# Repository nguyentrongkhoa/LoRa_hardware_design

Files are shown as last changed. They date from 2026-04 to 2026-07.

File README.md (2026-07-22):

# 🌍 Overview

This is a 4-layer RF-LoRa-PCB design for my bachelor thesis. The design entails:

1. LoRa transceiver embedded within the STM32WL55 microcontroller
2. BMV080 sensor and BME680 breakout board from Bosch
3. L80-R GPS module from Quectel to test radio coverage
4. SPV1050 solar energy harvesting module
5. BQ24074 battery charging module with USB-C connector

<table>
  <tr>
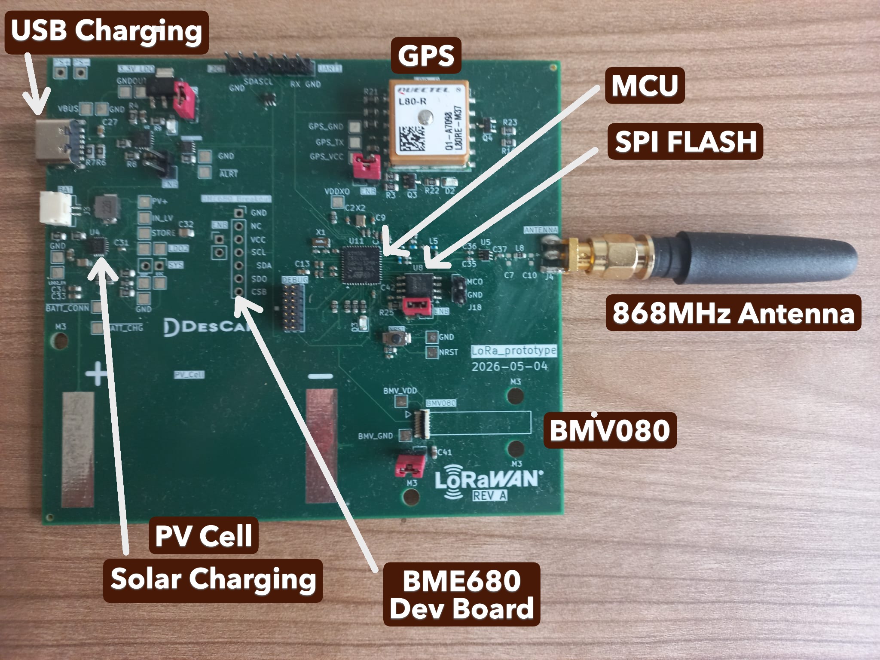
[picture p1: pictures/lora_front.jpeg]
Front
    <td></td>
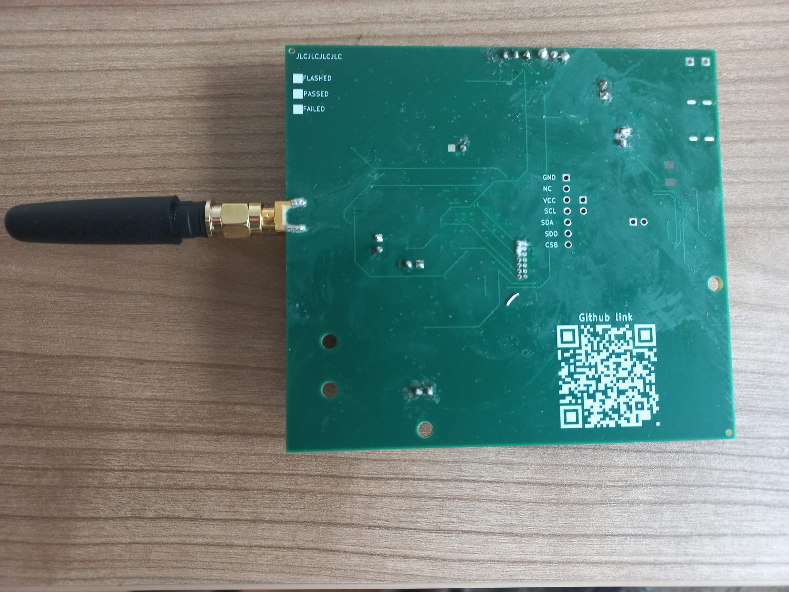
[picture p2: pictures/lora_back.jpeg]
Back
    <td></td>
  </tr>
</table>

<details>
<summary><h1>📋STM32WL55CCU6 pinout configuration</h1>  </summary>

|**Pin number** | **Pin name**| **Description**|
|---|---|---|
|PA0|Blinky LED|To quick test if flashing works
|PA2|VCP_TX|STLinkV3 virtual com port|
|PA3|VCP_RX|STLinkV3 virtual com port|
|PA4|NSS1|SPI1 slave select|
|PA5|SCK1|SPI1 clock signal|
|PA6|MISO1|SPI1|
|PA7|MOSI1|SPI1|
|PA8|MCO|Hook up to oscilloscope to test TCXO 32MHz output|
|PA9 |TX1|UART to communicate with GPS 
|PA10|RX1|UART to communicate with GPS 
|PA12|GPS_RESET|
|PA13|SWDIO|for flashing/debugging
|PA14|SWDCK|for flashing/debugging
|PB2|ALRT|From MAX17048 fuel gauge when battery is low
|PB3|SWO|for flashing/debugging
|PB6|SCL1|I2C to communicate with gas sensors and fuel gauge
|PB7|SDA1|I2C to communicate with gas sensors and fuel gauge
|PB8 |RF_SW_V2| RF switch control input 2 (to choose between receive and transmit)
|PB12|RF_SW_V1| RF switch control input 1
</details>

<details>
  
<summary><h1>🔌Testpoints setup</h1> </summary>

|**Testpoint name** | **Description**| **Expected result**
|---|---|---|
|VBUS|USB voltage|5V when USB is connected
|OUT|output of BQ24074 battery charging module|4.2V when battery is full, ~3.5V when battery empty
|ALRT|MAX17048 fuel gauge alert signal when battery is low|3.3V when battery is full, 0V when empty 

</details>

<details>
<summary><h1>🔍PCB inspection result</h1></summary>
  
## Detailed testing
### Visual inspection
### Electrical tests

#### Power consumption 

</details>

<details>
<summary><h1>✅<b>TODOs for next version</b></h1></summary>

- [ ] Replace SMA connector from Samtec with a cheaper one (see notes in schematic)
- [ ] Tune the antenna side matching network with NanoVNA
- [ ] Remove GPS module since TTFF (time-to-first-fix) is too long
- [ ] Move BMV080 away from MCU
- [ ] Fix VCP (virtual COM port) connections so that debug prints can be displayed in the host comp's terminal
- [ ] Fix PCB edge cut so that it's rectangular and not jagged
- [ ] Fix BMV080 orientation (so that it does not overlap solar cell)
- [ ] Remove USB charging (including BQ24072 charging IC), since the 3.3V LDO of the SPV1050 with max 200 mA can supply the       whole system

</details>

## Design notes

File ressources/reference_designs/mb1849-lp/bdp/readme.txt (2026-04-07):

******************************************************************************
* @file         readme.txt
* @author   MCD Application Team
* @version 1.0
* @date      22-June-2022 
* @brief      Reference_Design_STM32WL_BGA73_4L_IPD_LowPower board manufacturing files package
******************************************************************************
* COPYRIGHT(c) 2022 STMicroelectronics
*
* The Open Platform License Agreement (“Agreement”) is a binding legal contract
* between you ("You") and STMicroelectronics International N.V. (“ST”), a
* company incorporated under the laws of the Netherlands acting for the purpose
* of this Agreement through its Swiss branch 39, Chemin du Champ des Filles,
* 1228 Plan-les-Ouates, Geneva, Switzerland.
*
* By using the enclosed reference designs, schematics, PC board layouts, and
* documentation, in hardcopy or CAD tool file format (collectively, the
* “Reference Material”), You are agreeing to be bound by the terms and
* conditions of this Agreement. Do not use the Reference Material until You
* have read and agreed to this Agreement terms and conditions. The use of
* the Reference Material automatically implies the acceptance of the Agreement
* terms and conditions.
*
* The complete Open Platform License Agreement can be found on www.st.com/opla.
******************************************************************************

========================
* 1.0 - 22-June-2022
========================
    + First official release.
	Manufacturing files and differents BOM variants for the board MB1849-LP

******************* (C) COPYRIGHT 2022 STMicroelectronics *****END OF FILE

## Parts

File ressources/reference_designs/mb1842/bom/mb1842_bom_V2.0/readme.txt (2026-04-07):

******************************************************************************
* @file         readme.txt
* @author   MCD Application Team
* @version 2.0
* @date      28-April-2025 
* @brief      STM32WL_BGA73 manufacturing files package
******************************************************************************
* COPYRIGHT(c) 2025 STMicroelectronics
*
* The Open Platform License Agreement (“Agreement”) is a binding legal contract
* between you ("You") and STMicroelectronics International N.V. (“ST”), a
* company incorporated under the laws of the Netherlands acting for the purpose
* of this Agreement through its Swiss branch 39, Chemin du Champ des Filles,
* 1228 Plan-les-Ouates, Geneva, Switzerland.
*
* By using the enclosed reference designs, schematics, PC board layouts, and
* documentation, in hardcopy or CAD tool file format (collectively, the
* “Reference Material”), You are agreeing to be bound by the terms and
* conditions of this Agreement. Do not use the Reference Material until You
* have read and agreed to this Agreement terms and conditions. The use of
* the Reference Material automatically implies the acceptance of the Agreement
* terms and conditions.
*
* The complete Open Platform License Agreement can be found on www.st.com/opla.
******************************************************************************

========================
* 2.0 - 28-April-2025
========================
    + Replacing TCXO part number.
	Updated the TCXO part number across various MB1842 BOM variants because the NT2016SA-32M-END4263A is obsolete and no longer manufactured.

========================
* 1.0 - 29-March-2022
========================
    + First official release.
	Manufacturing files and differents BOM variants for the board MB1842
  
******************* (C) COPYRIGHT 2025 STMicroelectronics *****END OF FILE

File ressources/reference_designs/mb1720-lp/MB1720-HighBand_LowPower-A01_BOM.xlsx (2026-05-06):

 |  |  | Bill of materials
 |  |  | Board reference: | MB1720
 |  |  | Variant: | HighBand_LowPower
 |  |  | PCB revision: | A
 |  |  | Assembly revision: | 01
 |  |  | Date: | 3/30/2022
Designator | Description | Value | Package | Manufacturer | Manufacturer_Part_Number | Fitted | Quantity
C1, C6, C10, C14, C16, C35 | Capacitor, MLCC, 4.7uF, 16V, X5R, 10%, 0603, T=0.8mm, Capacitor, MLCC, 4.7 uF, 16V, X5R, 10%, 0603, T=0.8mm, Capacitor, MLCC, 100 nF, 16V, X5R, 10%, 0603, T=0.8mm | 4.7uF | 0603 | YAGEO | CC0603KRX5R7BB475 | Fitted | 6
C2, C3, C4, C5, C7, C11, C12 | Capacitor, MLCC, 100nF, 16V, X7R, 10%, 0402, T=0,5mm | 100nF | 0402 | YAGEO | CC0402KRX7R7BB104 | Fitted | 7
C8, C9, C26, C31 | Capacitor, MLCC, 6.8pF, 50V, NPO, +-0.1pF, 0402, T=0.5mm | 5.1pF | 0402 | YAGEO | CC0402CRNPO9BN5R1 | Fitted | 4
C13, C23 | Capacitor, MLCC, 1nF, 16V, X7R, 10%, 0402, T=0.5mm | 1nF | 0402 | YAGEO | CC0402KRX7R7BB102 | Fitted | 2
C15 | Capacitor, MLCC,47nF, 16V, X7R, 10%, 0402, T=0.5mm | 47 nF | 0402 | MURATA | GCM155R71E473KA55 | Fitted | 1
C17, C22, C24 | RF Capacitor | 3 pF | 0402 | MURATA | GJM1555C1H3R0CB01 | Fitted | 3
C18 | Capacitor, MLCC,68pF, 50V, C0G, 1%, 0402, T=0.5mm | 68 pF | 0402 | MURATA | GCM1555C1H680JA16 | Fitted | 1
C19, C25 | RF Capacitor | 68 pF, 68pF | 0402 | MURATA | GRM1555C1HR68WB01D | Fitted | 2
C20 | RF Capacitor | 0.7 pF | 0402 | MURATA | GJM1555C1HR70BB01 | Fitted | 1
C21 | RF Capacitor | 8 pF | 0402 | MURATA | GJM1555C1H8R0DB01 | Fitted | 1
C27 | RF Capacitor | 100nF | 0402 | MURATA | NRND_GRM155R71A104KA01 | Fitted | 1
C30 | RF Capacitor | 4.7 pF | 0402 | MURATA | GJM1555C1H4R7CB01 | Fitted | 1
C32, C33, C34 | Capacitor, MLCC, 33pF, 50V, NPO, 2%, 0402, T=0,5mm | 33pF | 0402 | YAGEO | CC0402JRNPO9BN330 | Fitted | 3
C36, C37 | 10pF ±1% 50V Ceramic Capacitor C0G, NP0 0402 (1005 Metric) | 10 pF | 0402 | MURATA | GJM1555C1H100FB01D | Fitted | 2
CN1, CN2 | Connector right-angle, pitch 2.54mm, 20 contacts |  |  | SAMTEC | TSW-120-07-L-S | Fitted | 2
J1, J2 | Header 1x2 Through hole 2.54mm |  |  | MOLEX | 22-03-2021 | Fitted | 2
J4 | SMA Jack, Edge Mount, 50 Ohms |  |  | SAMTEC | SMA-J-P-H-ST-EM1 | Fitted | 1
L1 | SMD Chip ferrite bead, 600R@100MHz +/-25%, 350mA, 500mohm DC, 0603, T=0.8mm | 600R @ 100MHz | 0603 | TAI-TECH | FCM1608KF-601T03 | Fitted | 1
L2 | MLZ2012 Multilayer Shielded Inductor 15µH, ±5% | 15uH | 0805 | TDK | MLZ2012M150W | Fitted | 1
L3 | RF Inductor | 47 nH | 0402 | MURATA | LQW15AN47NG00 | Fitted | 1
L4 | RF Inductor | 2.6 nH | 0402 | MURATA | LQW15AN2N6G00 | Fitted | 1
L5 | RF Inductor | 10 nH | 0402 | MURATA | LQW15AN10NG00 | Fitted | 1
L6 | Résistance 0 ohm | 3.9nH | 0402 | MURATA | LQW15AN3N9B00# | Fitted | 1
L7 | Resistor 0Ohm | 0 | 0402 | YAGEO | AA0402JR-070RL | Fitted | 1
L8 | RF Inductor | 11 nH | 0402 | MURATA | LQW15AN11NG00 | Fitted | 1
R1 | Resistor,10K,0603,1%,1/10W | 10K | 0603 | YAGEO | RC0603FR-0710KL | Fitted | 1
R2, R3 | Resistor,100R,0402,1%,1/16W | 100R | 0402 | YAGEO | RC0402FR-07100RL | Fitted | 2
SB10 | Solder Bridge 0R (Populated with 0 Ohm soldered on the lower path) | 0, 0 ohm | 0402 |  |  | Fitted | 1
U4 | STM32WL ARM MCU Multiprotocol LPWAN 32-bit Arm Cortex-M4 MCUs LoRa (G)FSK-MSK BPSK |  |  | STMicroelectronics | STM32WLE5CC | Fitted | 1
SB1, SB2, SB3, SB6, SB8, SB11, SB13, SB14 | Solder Bridge 0R [0402] (Populated with 0 Ohm) | 0, 0 ohm |  | Vishay / Dale | RCS04020000Z0ED | Fitted | 8
SB4, SB5, SB7, SB9 | Solder Bridge Open [0402] (Unpopulated) |  |  |  |  | Fitted | 4
U2 | ESD protection 6V1 | ESDALC6V1-1U2 |  | STMICROELECTRONICS | ESDALC6V1-1U2 | Fitted | 1
U3 | DC switch - Ultra-Low SPDT analog switch |  |  | INFINEON | BGS12SN6 | Fitted | 1
X1 | Crystal 32.768kHz, 6pF, -+20PPM, R=80K, SMD | 32.768KHz | 2.05x1.2mm | NDK | NX2012SA-32.768KHZ-EXS00A-MU00527 | Fitted | 1
X2 | Crystal 32 MHz, 8pF, -+10 PPM, R=60Ω, SMD | 32MHz | 2x1.6mm | NDK | NX2016SA-32MHZ-EXS00A-CS06654 | Fitted | 1
C28 | RF Capacitor |  | 0402 |  |  | Not Fitted | 0
C29 | RF Capacitor |  | 0402 |  |  | Not Fitted | 0

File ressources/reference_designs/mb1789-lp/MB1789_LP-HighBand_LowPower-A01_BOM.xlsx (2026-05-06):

 |  |  | Bill of materials
 |  |  | Board reference: | MB1789_LP
 |  |  | Variant: | HighBand_LowPower
 |  |  | PCB revision: | A
 |  |  | Assembly revision: | 01
 |  |  | Date: | 4/1/2022
Designator | Description | Value | Package | Manufacturer | Manufacturer_Part_Number | Fitted | Quantity
C1, C6, C10, C14 | Capacitor, MLCC, 4.7uF, 16V, X5R, 10%, 0603, T=0.8mm, Capacitor, MLCC, 4.7 uF, 16V, X5R, 10%, 0603, T=0.8mm | 4.7uF | 0603 | YAGEO | CC0603KRX5R7BB475 | Fitted | 4
C2, C3, C4, C5, C7, C11, C12, C110 | Capacitor, MLCC, 100nF, 16V, X7R, 10%, 0402, T=0,5mm, Multilayer Ceramic Capacitors MLCC - SMD/SMT 0201 33pF 25volts C0G 5% | 100nF | 0402 | YAGEO | CC0402KRX7R7BB104 | Fitted | 8
C8, C9 | Capacitor, MLCC, 6.8pF, 50V, NPO, +-0.1pF, 0402, T=0.5mm | 5.1pF | 0402 | YAGEO | CC0402CRNPO9BN5R1 | Fitted | 2
C15, C18 | Capacitor, MLCC,47nF, 16V, X7R, 10%, 0402, T=0.5mm, Capacitor, MLCC,68pF, 50V, C0G, 1%, 0402, T=0.5mm | 100nF | 0402 | MURATA | NRND_GRM155R71A104KA01 | Fitted | 2
C19 | MLCC 33 pF 50V 2% 0402 | 33 pF | 0402 | MURATA | GJM1555C1H330GB01 | Fitted | 1
C20 | MLCC 8.7 pF, 50 VDC, C0G(NP0), +/-0.1 pF, [0402] | 8.7 pF | 0402 | MURATA | GJM1555C1H8R7BB01 | Fitted | 1
C21 | MLCC 3.3 pF 50Volts C0G +/-0.1pF [0402] | 3.3 pF | 0402 | YAGEO | GJM1555C1H3R3BB01 | Fitted | 1
C30 | Multilayer Ceramic Capacitors MLCC - SMD/SMT 0402 3.9pF 50Volts C0G +/-0.25pF | 3.9 pF | 0402 | MURATA | GJM1555C1H3R9CB01 | Fitted | 1
C32, C33, C34, C36, C37, C320 | Multilayer Ceramic Capacitors MLCC - SMD/SMT 0201 33pF 25volts C0G 5%, Capacitor, MLCC, 33pF, 50V, NPO, 2%, 0402, T=0,5mm | 33pF | 0402 | YAGEO | CC0402JRNPO9BN330 | Fitted | 6
C35 | Condensateurs céramique multicouches MLCC - CMS 0402 | 4 pF | 0402 | MURATA | GJM1555C1H4R0CB01 | Fitted | 1
CN1, CN2, J1, J2 | Connector, [NoValue] |  |  |  |  | Fitted | 4
J4 | SMA End Launch Jack 1.0 mm Board, 50 ohm |  |  | COAX CONNECTORS LTD | 30-462-D3-1.1mm | Fitted | 1
L1 | SMD Chip ferrite bead, 600R@100MHz +/-25%, 350mA, 500mohm DC, 0603, T=0.8mm | 600R @ 100MHz | 0603 | TAI-TECH | FCM1608KF-601T03 | Fitted | 1
L2 | MLZ2012 Multilayer Shielded Inductor 15µH, ±5% | 15uH | 0805 | TDK | MLZ2012M150W | Fitted | 1
L3 | Inductor, 47 nH, 2%, 210 mA, 0402 | 47 nH | 0402 | MURATA | LQW15AN47NG00 | Fitted | 1
L4 | Inductor, 9.5 nH, +-2%, 540mA, 0402 | 9.5 nH | 0402 | MURATA | LQW15AN9N5G00 | Fitted | 1
L5, R10, R100, R101 | Resistor,0R,0402,5%,1/16W | NM, 0, 0R | R0402, 0402 | YAGEO | RC0402JR-070RL | Fitted | 4
L8 | Inductor, 10 nH, +-2%, 500mA, 0402 | 10 nH | 0402 | MURATA | LQW15AN10NG00 | Fitted | 1
L9 | Inductor, 3.9nH, +-0.1nH, 750mA, 0402 | 3.9nH | 0402 | MURATA | LQW15AN3N9B00# | Fitted | 1
L10 | Inductor, 3nH, +-0.1nH, 1350mA, 0402 | 3 nH | 0402 | MURATA | LQW15AN3N0B80 | Fitted | 1
R1 | Resistor,10K,0603,1%,1/10W | 10K | 0603 | YAGEO | RC0603FR-0710KL | Fitted | 1
SB11, SB13, SB15 | Solder Jumper - Close, Solder Bridge 0R [0402] (Populated with 0 Ohm) | [NoParam], 0 |  | Vishay / Dale | RCS04020000Z0ED | Fitted | 3
SB14 | Solder Bridge Open [0402] (Unpopulated) |  |  |  |  | Fitted | 1
U2 | ESD protection 6V1 | ESDALC6V1-1U2 |  | STMICROELECTRONICS | ESDALC6V1-1U2 | Fitted | 1
U4 | STM32WL ARM MCU Multiprotocol LPWAN 32-bit Arm Cortex-M4 MCUs LoRa (G)FSK-MSK BPSK |  |  | STMicroelectronics | STM32WLE5CC | Fitted | 1
X1 | Crystal 32.768kHz, 6pF, -+20PPM, R=80K, SMD | 32.768KHz | 2.05x1.2mm | NDK | NX2012SA-32.768KHZ-EXS00A-MU00527 | Fitted | 1
X2 | Crystal 32 MHz, 8pF, -+10 PPM, R=60Ω, SMD | 32MHz | 2x1.6mm | NDK | NX2016SA-32MHZ-EXS00A-CS06654 | Fitted | 1
C17 | MLCC [0402] 2.7pF 50Volts C0G +/-0.1pF | 2.7 pF | 0402 | muRata | GJM1555C1H2R7BB01 | Not Fitted | 0
C22 | MLCC 1.3 pF 50 VDC +/-0.1 pF C0G [0402] | 1.3 pF | 0402 | MURATA | GJM1555C1H1R3BB01 | Not Fitted | 0
C24 | Multilayer Ceramic Capacitors MLCC - SMD/SMT 0402 3.6pF 50Volts C0G +/-0.05pF | 100nF | 0402 | MURATA | GJM1555C1H3R6WB01 | Not Fitted | 0
C26, C31 | Capacitor, MLCC, 6.8pF, 50V, NPO, +-0.1pF, 0402, T=0.5mm | 5.1pF | 0402 | YAGEO | CC0402CRNPO9BN5R1 | Not Fitted | 0
C28 | MLCC 0402 3.3 pF 50 VDC C0G +/-0.1 pF | 3.3 pF | 0402 | muRata | GJM1555C1H3R3BB01 | Not Fitted | 0
C38 | Multilayer Ceramic Capacitors MLCC - SMD/SMT 0201 33pF 25volts C0G 5% | 100nF | 0402 | MURATA | NRND_GRM155R71A104KA01 | Not Fitted | 0
L6 | High Frequency Inductor, 3.3 nH, LQW15A_10 Series, 900 mA, 0402 | 3.3 nH | 0402 | muRata | LQW15AN3N3D10 | Not Fitted | 0

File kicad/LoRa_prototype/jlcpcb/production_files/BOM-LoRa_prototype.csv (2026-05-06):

Comment | Designator | Footprint | LCSC | Quantity
0 | L8 | L_0603_1608Metric | C21189 | 1
0.75pF | C22 | C_0402_1005Metric | C76914 | 1
100K | R10 | R_0805_2012Metric | C149504 | 1
100K | R28,R29 | R_0603_1608Metric | C25803 | 2
100nF | C40 | C_0603_1608Metric | C14663 | 1
100nF | C31,C39,C42,C44,C46,C50,C6 | C_0402_1005Metric | C1525 | 7
100pF | C35,C36,C37 | C_0402_1005Metric | C1546 | 3
10K | R25,R8 | R_0805_2012Metric | C17414 | 2
10K | R1 | R_0603_1608Metric | C25804 | 1
10nF | C51 | C_0402_1005Metric | C15195 | 1
10nH | L5,L6 | L_0402_1005Metric | C184029 | 2
10uF | C38,C41 | C_0603_1608Metric | C19702 | 2
15uH | L1 | L_0402_1005Metric | C3221788 | 1
18pF | C4,C8 | C_0402_1005Metric | C1549 | 2
1K | R20,R21,R22,R5,R9 | R_0805_2012Metric | C17513 | 5
1K | R30 | R_0603_1608Metric | C21190 | 1
1M | R11,R12,R13,R18 | R_0805_2012Metric | C17514 | 4
1nF | C2,C9 | C_0402_1005Metric | C1523 | 2
1uF | C27 | C_0603_1608Metric | C15849 | 1
1uF | C52 | C_0402_1005Metric | C52923 | 1
2.7nH | L4 | L_0402_1005Metric | C91239 | 1
200K | R17 | R_0805_2012Metric | C17539 | 1
22uH | L7 | PSPMAA0402-220M-ANP | C5273842 | 1
2K | R4 | R_0805_2012Metric | C17604 | 1
33pF | C45,C48,C49 | C_0402_1005Metric | C1562 | 3
3pF | C21,C25,C26 | C_0402_1005Metric | C88891 | 3
4.7K | R16,R2 | R_0805_2012Metric | C17673 | 2
4.7K | R26,R27 | R_0603_1608Metric | C23162 | 2
4.7pF | C24 | C_0402_1005Metric | C85883 | 1
4.7uF | C28,C29,C30,C33,C34 | C_0603_1608Metric | C19666 | 5
4.7uF | C43,C47 | C_0402_1005Metric | C23733 | 2
470K | R15 | R_0805_2012Metric | C17709 | 1
470nF | C13 | C_0603_1608Metric | C1623 | 1
47K | R23,R3 | R_0805_2012Metric | C17713 | 2
47nF | C18 | C_0603_1608Metric | C1622 | 1
47nH | L3 | L_0402_1005Metric | C22334 | 1
5.1K | R6,R7 | R_0805_2012Metric | C27834 | 2
5.6K | R19 | R_0805_2012Metric | C4382 | 1
68pF | C19,C23 | C_0402_1005Metric | C76977 | 2
8.2pF | C20 | C_0402_1005Metric | C88898 | 1
82K | R14 | R_0603_1608Metric | C23254 | 1
AS179-92LF | U5 | SOT-363_SC-70-6 | C83422 | 1
BAT | J3 | JST_GH_SM02B-GHS-TB_1x02-1MP_P1.25mm_Horizontal | C189893 | 1
BMV080 | U9 | CON_5035661302_MOL | C587979 | 1
BQ24074RGTT | U2 | VQFN-16-1EP_3x3mm_P0.5mm_EP1.6x1.6mm | C54313 | 1
CHG | D1 | LED_0805_2012Metric | C2297 | 1
Conn_ST_STDC14 | J1 | PinHeader_2x07_P1.27mm_Vertical | C3333025 | 1
L80-R | U6 | Quectel_L80-R | C3029061 | 1
LED | D2 | LED_0805_2012Metric | C2296 | 1
LSE | X1 | Crystal_SMD_3215-2Pin_3.2x1.5mm | C32346 | 1
MAX17048 | U3 | SON50P200X200X80-9N | C2682616 | 1
NRST | SW1 | TS-1088-AR02016 | C720477 | 1
NT2016SF | X2 | NT2016SF TCXO | C36338880 | 1
PESD3V3L4UG | D4 | DIO_PESD3V3L4UG | C52741412 | 1
SPV1050 | U4 | QFN40P300X300X100-21N | C5181469 | 1
SS8050 | Q3,Q4 | SOT-23 | C2150 | 2
STM32WL55CCUx | U11 | QFN-48-1EP_7x7mm_P0.5mm_EP5.6x5.6mm | C5270474 | 1
TC1262-33 | U1 | SOT-223-3 | C52507 | 1
USB_C_Receptacle_PowerOnly_6P | J2 | UC17-0B06F68011 | C36936554 | 1
W25Q16JVSS | U8 | SOIC-8_5.3x5.3mm_P1.27mm | C131025 | 1
blinky | D3 | LED_0805_2012Metric | C2297 | 1
47uF | C32 | C_0805_2012Metric |  | 1

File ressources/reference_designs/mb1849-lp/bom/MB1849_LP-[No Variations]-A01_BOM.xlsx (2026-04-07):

 |  |  |  | Bill of materials
 |  |  |  | Board reference: | MB1849_LP
 |  |  |  | Variant: | None
 |  |  |  | PCB revision: | A
 |  |  |  | Assembly revision: | 01
 |  |  |  | Date: | 9/1/2022
Designator | Description | Value | Package | Manufacturer | Manufacturer_Part_Number | Fitted | Quantity
C1, C6, C10, C16, C35 | Capacitor, MLCC, 4.7uF, 16V, X5R, 10%, 0603, T=0.8mm | 4.7uF | C0603 | YAGEO | CC0603KRX5R7BB475 | Fitted | 5
C2, C3, C4, C5, C7, C11, C12, C24, C26, C31, C32, C37, C41, C110 | Capacitor, MLCC, 100nF, 16V, X7R, 10%, 0402, T=0,5mm | 100nF | C0402 | YAGEO | CC0402KRX7R7BB104 | Fitted | 14
C8, C9 | Capacitor, MLCC, 5.1 pF, 50V, NPO, +-0.1pF, 0402, T=0.5mm | 5.1 pF | C0402 | YAGEO | CC0402CRNPO9BN5R1 | Fitted | 2
C13, C23 | Multilayer ceramic capacitors X7R ±10%, 50V, Multilayer ceramic capacitors COG +/-5%, 50V | 1nF | C0201 | MURATA | GRM033R71H102KA12D | Fitted | 2
C200 | Multilayer ceramic capacitors COG +/-5%, 50V | 100pF | C0402 | MURATA | GRM0335C1H101GA01D | Fitted | 1
C14 | Multilayer Ceramic Capacitors MLCC - SMD/SMT 16V 0.47uF X5R 0603 10% | 0.47uF | C0603 | YAGEO | CC0603KRX5R7BB474 | Fitted | 1
C15 | Capacitor, MLCC,68pF, 50V, C0G, 1%, 0402, T=0.5mm | 68 pF | C0402 | MURATA | GRM1555C1E680JA01 | Fitted | 1
C17, C25 | Multilayer ceramic capacitors COG ±5%, 50V | 39 pF | C0201 | MURATA | GRM0335C1H390JA01D | Fitted | 2
C18 | Capacitor, MLCC,47nF, 16V, X7R, 10%, 0402, T=0.5mm | 47 nF | C0402 | MURATA | GRM155C71H473KE19 | Fitted | 1
C27, C28, C29 | Not connected | NC |  |  |  | Fitted | 3
SB11 | Not connected | NC
L3 | RF Inductor | 47nH | L0402 | MURATA | LQW15AN47NG00 | Fitted | 1
C33, C34 | Multilayer Ceramic Capacitors MLCC - SMD/SMT 0201 33pF 25volts C0G 5% | 33pF | C0201 | MURATA | GJM0335C1E330JB01D | Fitted | 2
C38 | Capacitor, MLCC, 10pF, 50V, NPO, +/-5%, 0402, T=0,5mm | 10pF | C0402 | YAGEO | CC0402JRNPO9BN100 | Fitted | 1
C39 | Capacitor, MLCC, 10nF, 16V, X7R, 10%, 0402, T=0.5mm | 10nF | C0402 | YAGEO | CC0402KRX7R7BB103 | Fitted | 1
CN1, CN2 | Connector right-angle, pitch 2.54mm, 20 contacts |  |  | SAMTEC | TSW-120-07-L-S | Fitted | 2
J4 | RF Connector, SMA End Launch Jack for 0.047 inch PCB, 50 Ohm, Flat Tab Contact |  |  | AMPHENOL | 132430 | Fitted | 1
L1 | Ferrite Beads 0603 600 OHM | 600R@100MHz | L0603 | MURATA | BLM18AG601SN1D | Fitted | 1
L2 | MLZ2012 Multilayer Shielded Inductor 15µH, ±5% | 15uH | L0805 | TDK | MLZ2012M150W | Fitted | 1
L7 | Thick Film Resistor ±5%, 1/20W | 0R | L0201 | Vishay/Dale | CRCW02010000Z0ED | Fitted | 1
L11 | ferrite bead, 1400ohms at 1GHz, 250mA, 1.1ohms DC max | 1400R@1GHz | L0402 | MURATA | BLM15HG102SN1# | Fitted | 1
R1 | Resistor,10K,0603,1%,1/10W | 10K | R0603 | YAGEO | RC0603FR-0710KL | Fitted | 1
R2, R3 | Thick Film Resistors - SMD 1/20watt 100ohms 5% 200ppm | 100R | R0201 | Vishay / Dale | CRCW0201100RJNED | Fitted | 2
R6 | Resistor,220R,0402,1%,1/16W | 220R | R0402 | YAGEO | RC0402FR-07220RL | Fitted | 1
S1 | RF Shield Frame + Cover without apertures |  |  | Masach Tech | MS409-10 | Fitted | 1
SB1, SB2, SB8, SB14 | Solder Bridge 0R [0402] (Populated with 0 Ohm) | 0 |  | Vishay / Dale | RCS04020000Z0ED | Fitted | 4
SB3, SB6 | Thick Film Resistors - SMD 1/20watt ZEROohm Jumper | 0 |  | Vishay / Dale | CRCW02010000Z0ED | Fitted | 2
SB4, SB5, SB9 | Solder Bridge Open [0402] (Unpopulated) |  |  | NOT FITTED | NOT FITTED | Fitted | 3
U1 | Multiprotocol Wireless 32-bit MCUwith LPWAN Sub-GHz radio solution |  |  | STMICROELECTRONICS | STM32WL55JCU6 | Fitted | 1
U2 | ESD protection 6V1 |  |  | STMICROELECTRONICS | ESDALC6V1-1U2 | Fitted | 1
U3 | DC switch - Ultra-Low SPDT analog switch |  |  | INFINEON | BGS12SN6 | Fitted | 1
U4 | IPD STM STM32WL |  |  | STMICROELECTRONICS | IPD STM STM32WL | Fitted | 1
X1 | Crystal 32.768kHz, 6pF, -+20PPM, R=80K, SMD | 32.768KHz |  | NDK | NX2012SA 32.768KHz EXS00A-MU00527 | Fitted | 1
X3 | NT2016SA-32M-END4263A | 32MHz | 2016 size | NDK | NT2016SA-32M-END4263A | Fitted | 1

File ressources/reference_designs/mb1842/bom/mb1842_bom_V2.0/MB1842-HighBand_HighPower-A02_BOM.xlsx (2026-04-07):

 |  |  |  | Bill of materials
 |  |  |  | Board reference: | MB1842
 |  |  |  | Variant: | HighBand_HighPower
 |  |  |  | PCB revision: | A
 |  |  |  | Assembly revision: | 02
 |  |  |  | Date: | 4/28/2025
Designator | Description | Value | Package | Manufacturer | Manufacturer_Part_Number | Fitted | Quantity
C1, C6, C10, C16, C35 | Capacitor, MLCC, 4.7uF, 16V, X5R, 10%, 0603, T=0.8mm | 4.7uF | C0603 | YAGEO | CC0603KRX5R7BB475 | Fitted | 5
C2, C3, C4, C5, C7, C11, C12, C24, C26, C31, C32, C37, C41, C110 | Capacitor, MLCC, 100nF, 16V, X7R, 10%, 0402, T=0,5mm | 100nF | C0402 | YAGEO | CC0402KRX7R7BB104 | Fitted | 14
C8, C9 | Capacitor, MLCC, 5.1 pF, 50V, NPO, +-0.1pF, 0402, T=0.5mm | 5.1 pF |  | YAGEO | CC0402CRNPO9BN5R1 | Fitted | 2
C13, C23 | Capacitor, MLCC, 1nF, 16V, X7R, 10%, 0402, T=0.5mm | 1nF |  | YAGEO | CC0402KRX7R7BB102 | Fitted | 2
C14 | Multilayer Ceramic Capacitors MLCC - SMD/SMT 16V 0.47uF X5R 0603 10% | 0.47uF | C0603 | YAGEO | CC0603KRX5R7BB474 | Fitted | 1
C15 | Capacitor, MLCC,68pF, 50V, C0G, 1%, 0402, T=0.5mm | 68 pF |  | MURATA | GRM1555C1E680JA01 | Fitted | 1
C17 | RF Capacitor | 2.1 pF |  | MURATA | GJM1555C1H2R1BB01D | Fitted | 1
C18 | Capacitor, MLCC,47nF, 16V, X7R, 10%, 0402, T=0.5mm | 47 nF |  | MURATA | GRM155C71H473KE19 | Fitted | 1
C19, C25 | Capacitor, MLCC,68pF, 50V, C0G, 1%, 0402, T=0.5mm | 68pF |  | MURATA | GRM1555C1H680JA01 | Fitted | 2
C20 | RF Capacitor | 7.1 pF | C0402 | MURATA | GJM1555C1H7R1BB01 | Fitted | 1
C21 | RF Capacitor | 4 pF |  | MURATA | GJM1555C1H4R0CB01 | Fitted | 1
C22 | RF Capacitor | 0.8 pF |  | MURATA | GJM1555C1HR80BB01 | Fitted | 1
C27, SB4, SB7, SB10 | [NoValue], Solder Bridge Open [0402] (Unpopulated) |  |  | Not Fitted | Not Fitted | Fitted | 4
C28, C29, C30 | RF Capacitor | 3 pF | C0402, [NoParam] | MURATA | GJM1555C1H3R0CB01 | Fitted | 3
C33, C34 | Multilayer Ceramic Capacitors MLCC - SMD/SMT 0201 33pF 25volts C0G 5% | 33pF |  | MURATA | GJM0335C1E330JB01D | Fitted | 2
C36 | RF Capacitor | 2.4 pF |  | MURATA | GJM1555C1H2R4CB01 | Fitted | 1
C38 | Capacitor, MLCC, 10pF, 50V, NPO, +/-5%, 0402, T=0,5mm | 10pF | C0402 | YAGEO | CC0402JRNPO9BN100 | Fitted | 1
C39 | Capacitor, MLCC, 10nF, 16V, X7R, 10%, 0402, T=0.5mm | 10nF | C0402 | YAGEO | CC0402KRX7R7BB103 | Fitted | 1
CN1, CN2 | Connector right-angle, pitch 2.54mm, 20 contacts |  |  | SAMTEC | TSW-120-07-L-S | Fitted | 2
J1, J2 | Header 1x2 Through hole 2.54mm |  |  | MOLEX | 22-03-2021 | Fitted | 2
J4 | RF Connector, SMA End Launch Jack for 0.047 inch PCB, 50 Ohm, Flat Tab Contact |  |  | AMPHENOL | 132430 | Fitted | 1
L1 | Ferrite Beads 0603 600 OHM | 600R@100MHz |  | MURATA | BLM18AG601SN1D | Fitted | 1
L2 | MLZ2012 Multilayer Shielded Inductor 15µH, ±5% | 15uH |  | TDK | MLZ2012M150W | Fitted | 1
L3 | RF Inductor | 47 nF |  | MURATA | LQW15AN47NG00 | Fitted | 1
L4 | RF Inductor | 3.2 nH |  | MURATA | LQW15AN3N2B00 | Fitted | 1
L5 | RF Inductor | 8.2 nH |  | MURATA | LQW15AN8N2G00 | Fitted | 1
L6 | RF Inductor | 3.4 nH |  | MURATA | LQW15AN3N4C10 | Fitted | 1
L7 | RF Inductor | 9.1 nH |  | MURATA | LQW15AN9N1G00 | Fitted | 1
L8 | RF Inductor | 12 nH |  | MURATA | LQW15AN12NG00 | Fitted | 1
L11 | ferrite bead, 1400ohms at 1GHz, 250mA, 1.1ohms DC max | 1400R@1GHz | L0402 | MURATA | BLM15HG102SN1# | Fitted | 1
R1 | Resistor,10K,0603,1%,1/10W | 10K |  | YAGEO | RC0603FR-0710KL | Fitted | 1
R2, R3 | Resistor,100R,0402,1%,1/16W | 100R |  | YAGEO | RC0402FR-07100RL | Fitted | 2
R6 | Resistor,220R,0402,1%,1/16W | 220R | R0402 | YAGEO | RC0402FR-07220RL | Fitted | 1
RF BoM1 |  |  |  |  |  | Fitted | 1
S1 | RF Shield Frame + Cover without apertures |  |  | Masach Tech | MS409-10 | Fitted | 1
SB1, SB2, SB3, SB6, SB8, SB14 | Solder Bridge 0R [0402] (Populated with 0 Ohm) | [NoParam], 0 |  | Vishay / Dale | RCS04020000Z0ED | Fitted | 6
SB5, SB9, SB11 | Solder Bridge Open [0402] (Unpopulated) |  |  |  |  | Fitted | 3
U1 | Multiprotocol Wireless 32-bit MCUwith LPWAN Sub-GHz radio solution |  |  | STMICROELECTRONICS | STM32WL55JCU6 | Fitted | 1
U2 | ESD protection 6V1 |  |  | STMICROELECTRONICS | ESDALC6V1-1U2 | Fitted | 1
U3 | DC switch - Ultra-Low SPDT analog switch |  |  | INFINEON | BGS12SN6 | Fitted | 1
X1 | Crystal 32.768kHz, 6pF, -+20PPM, R=80K, SMD | 32.768KHz |  | NDK | NX2012SA 32.768KHz EXS00A-MU00527 | Fitted | 1
X3 | IQXT-205-3-30 is a 2.0 x 1.6mm SMD Temperature Compensated Crystal Oscillator (TCXO) | 32MHz | 2016 size | IQD | LFTCXO094776 | Fitted | 1

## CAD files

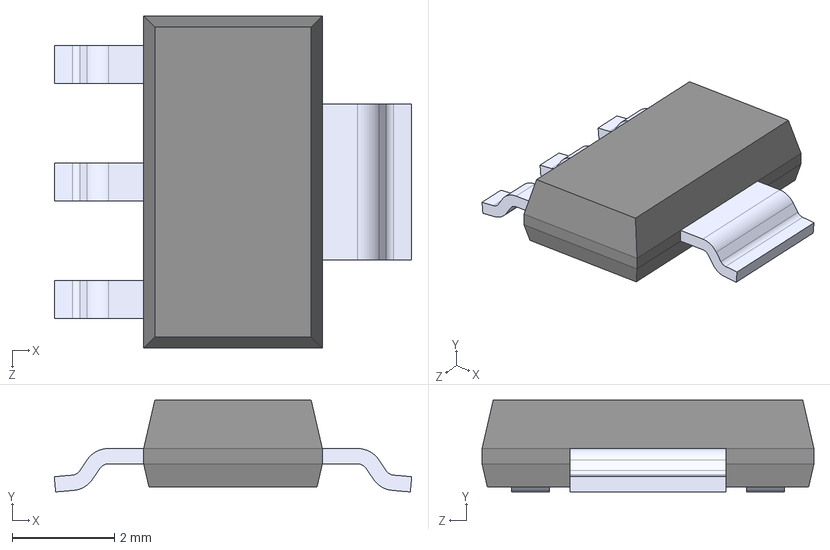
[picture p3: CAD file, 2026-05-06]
kicad/3d_models/TC1262-3.3VDB.step
7.00 x 1.80 x 6.50 mm

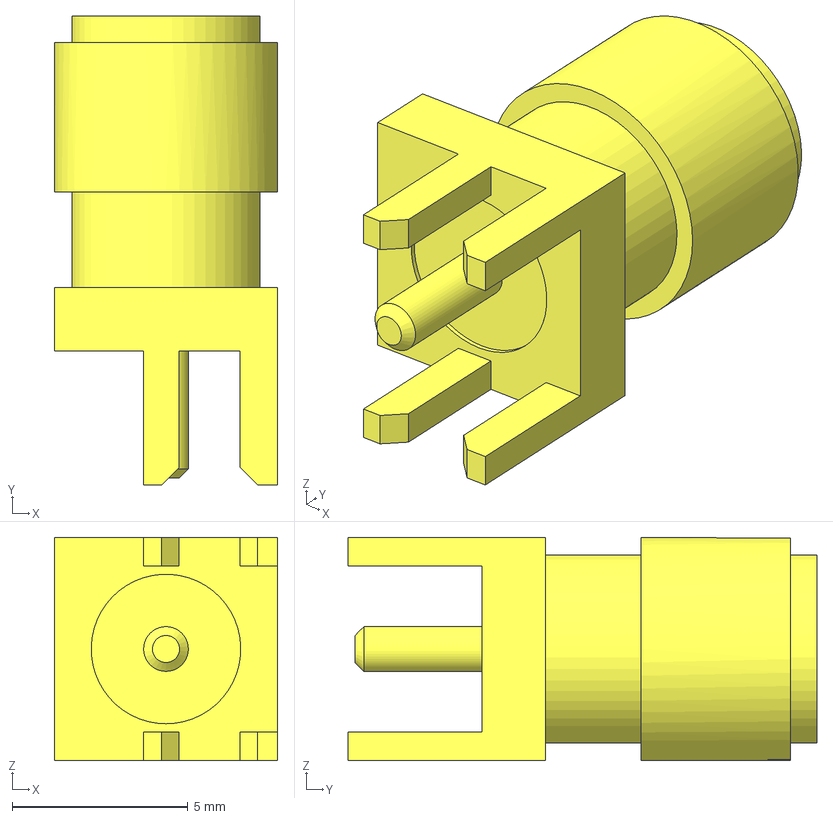
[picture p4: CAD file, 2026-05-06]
kicad/3d_models/SMA-J-P-H-ST-EM1.step
6.35 x 13.3 x 6.35 mm

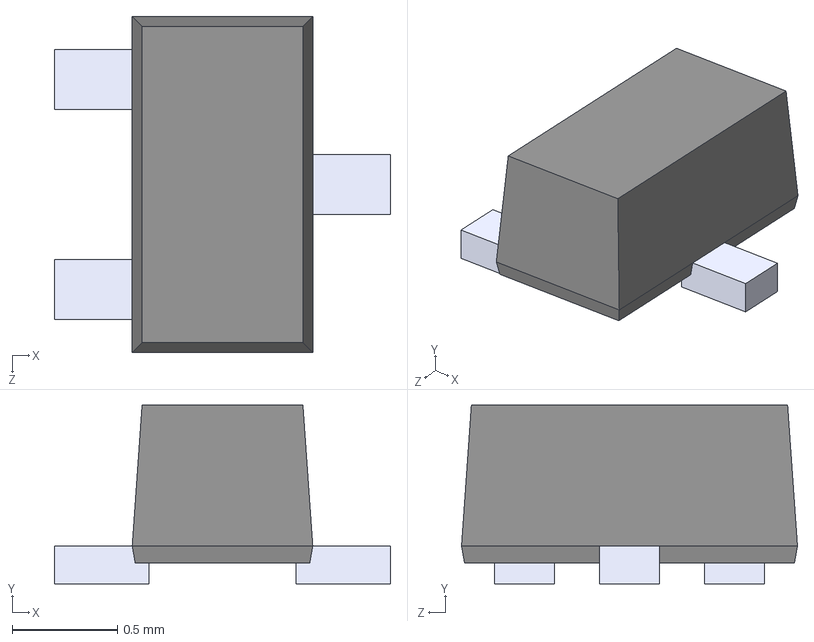
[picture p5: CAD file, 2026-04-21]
kicad/3d_models/DTC143ZEBTL.step
1.60 x 0.85 x 1.60 mm

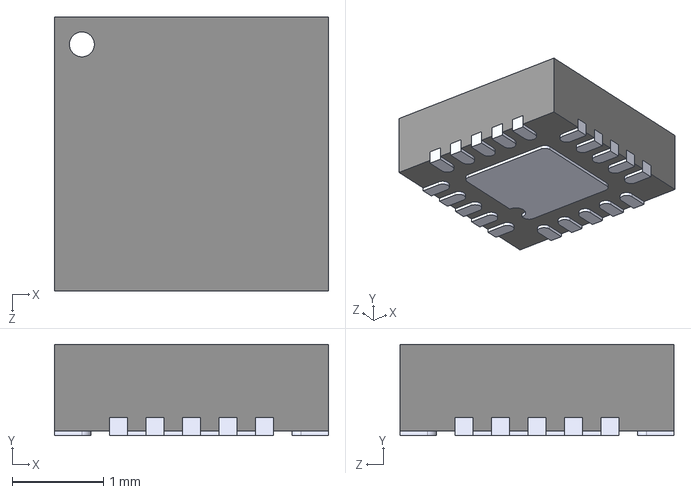
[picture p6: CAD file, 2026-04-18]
kicad/3d_models/SPV1050TTR.step
3.00 x 1.00 x 3.00 mm

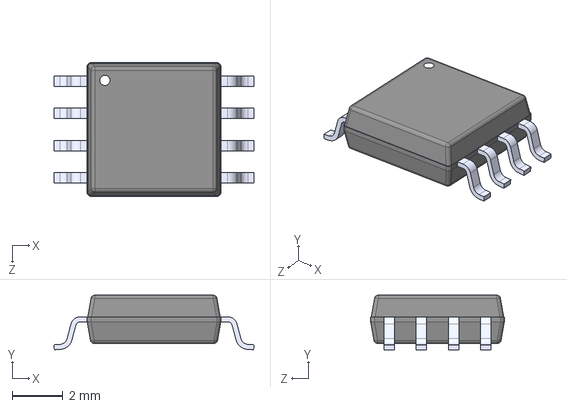
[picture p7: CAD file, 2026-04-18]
kicad/3d_models/W25Q16JVSSIQ.step
7.90 x 2.16 x 5.28 mm

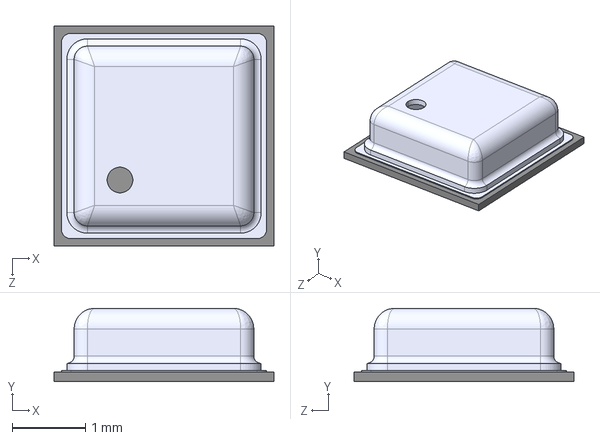
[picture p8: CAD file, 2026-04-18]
kicad/3d_models/BME688.step
3.00 x 1.00 x 3.00 mm

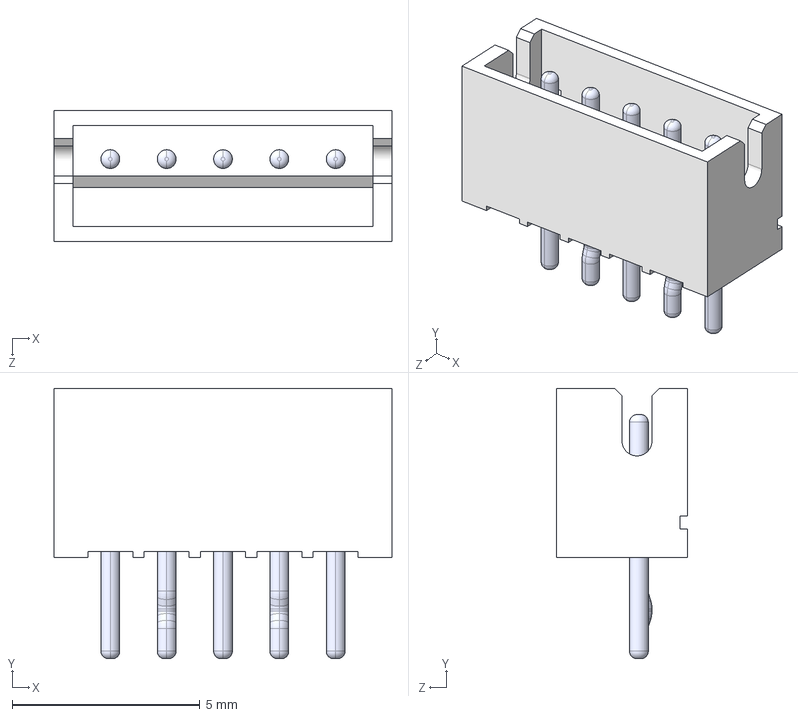
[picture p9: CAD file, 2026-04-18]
kicad/3d_models/B5B-ZR_LF__SN_.step
9.00 x 7.20 x 3.50 mm
BxB-ZR_5
pin_straight x 3
pin_Bent x 2

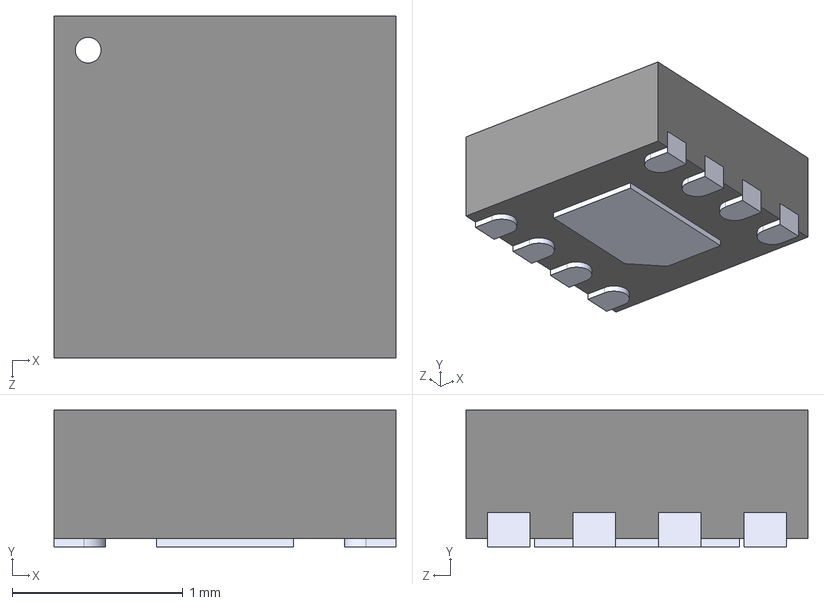
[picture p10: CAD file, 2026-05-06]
kicad/3d_models/MAX17048G_T10.step
2.00 x 0.8 x 2.00 mm

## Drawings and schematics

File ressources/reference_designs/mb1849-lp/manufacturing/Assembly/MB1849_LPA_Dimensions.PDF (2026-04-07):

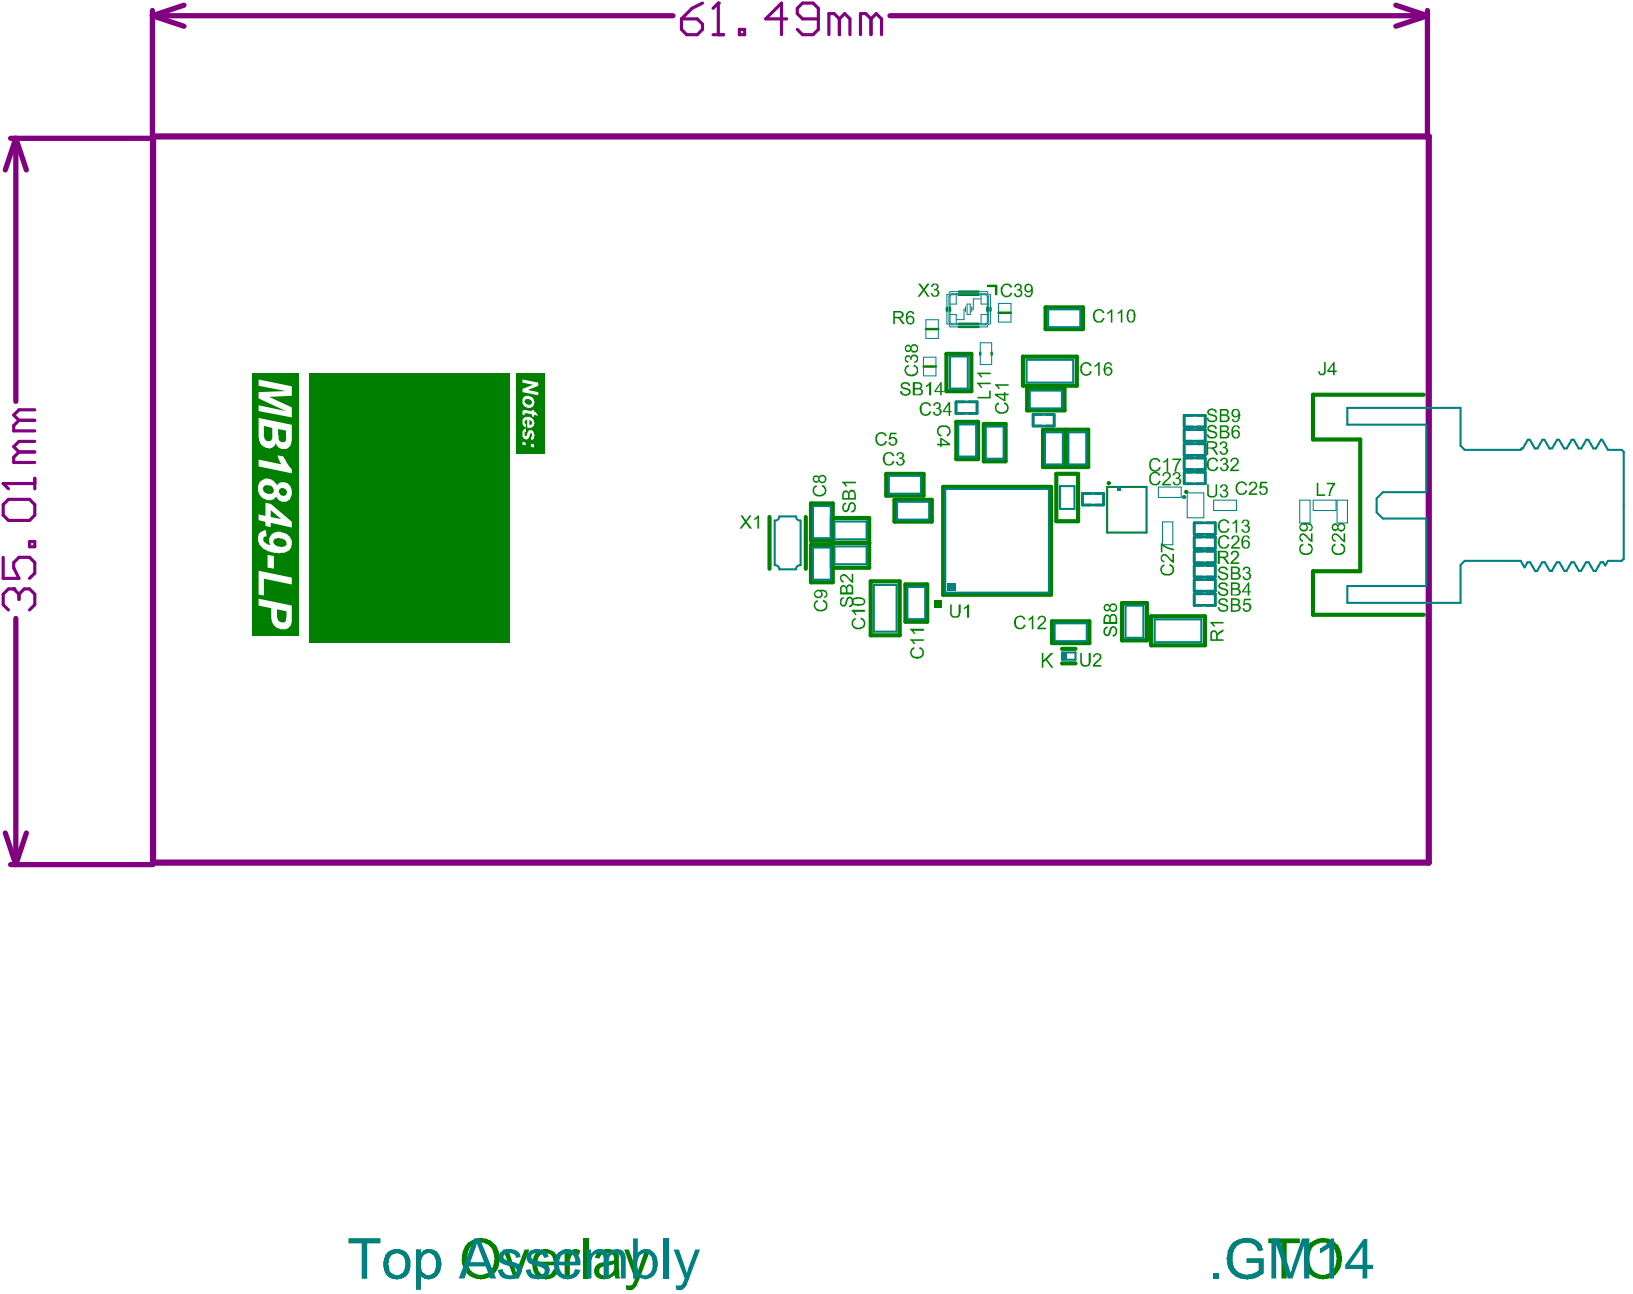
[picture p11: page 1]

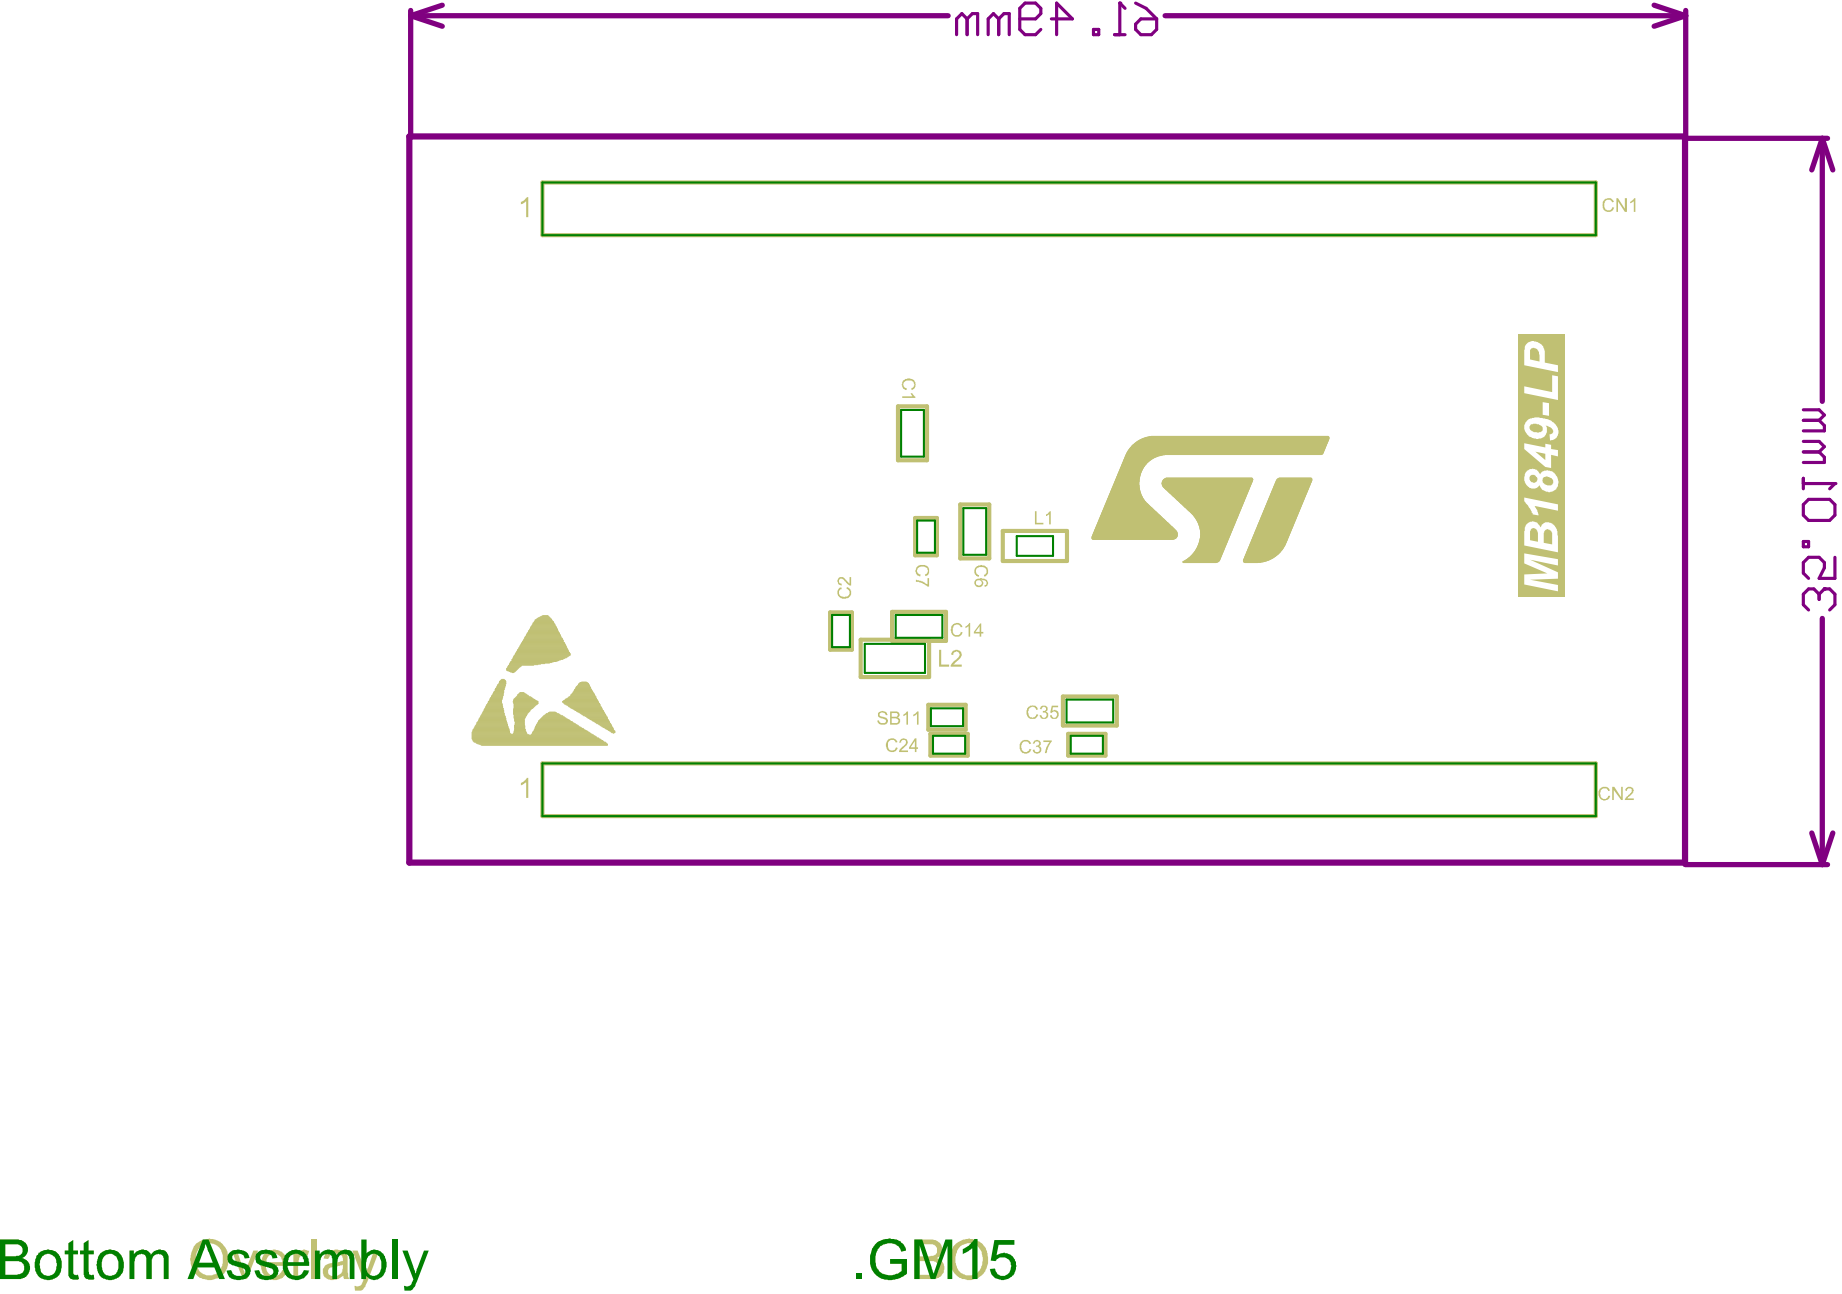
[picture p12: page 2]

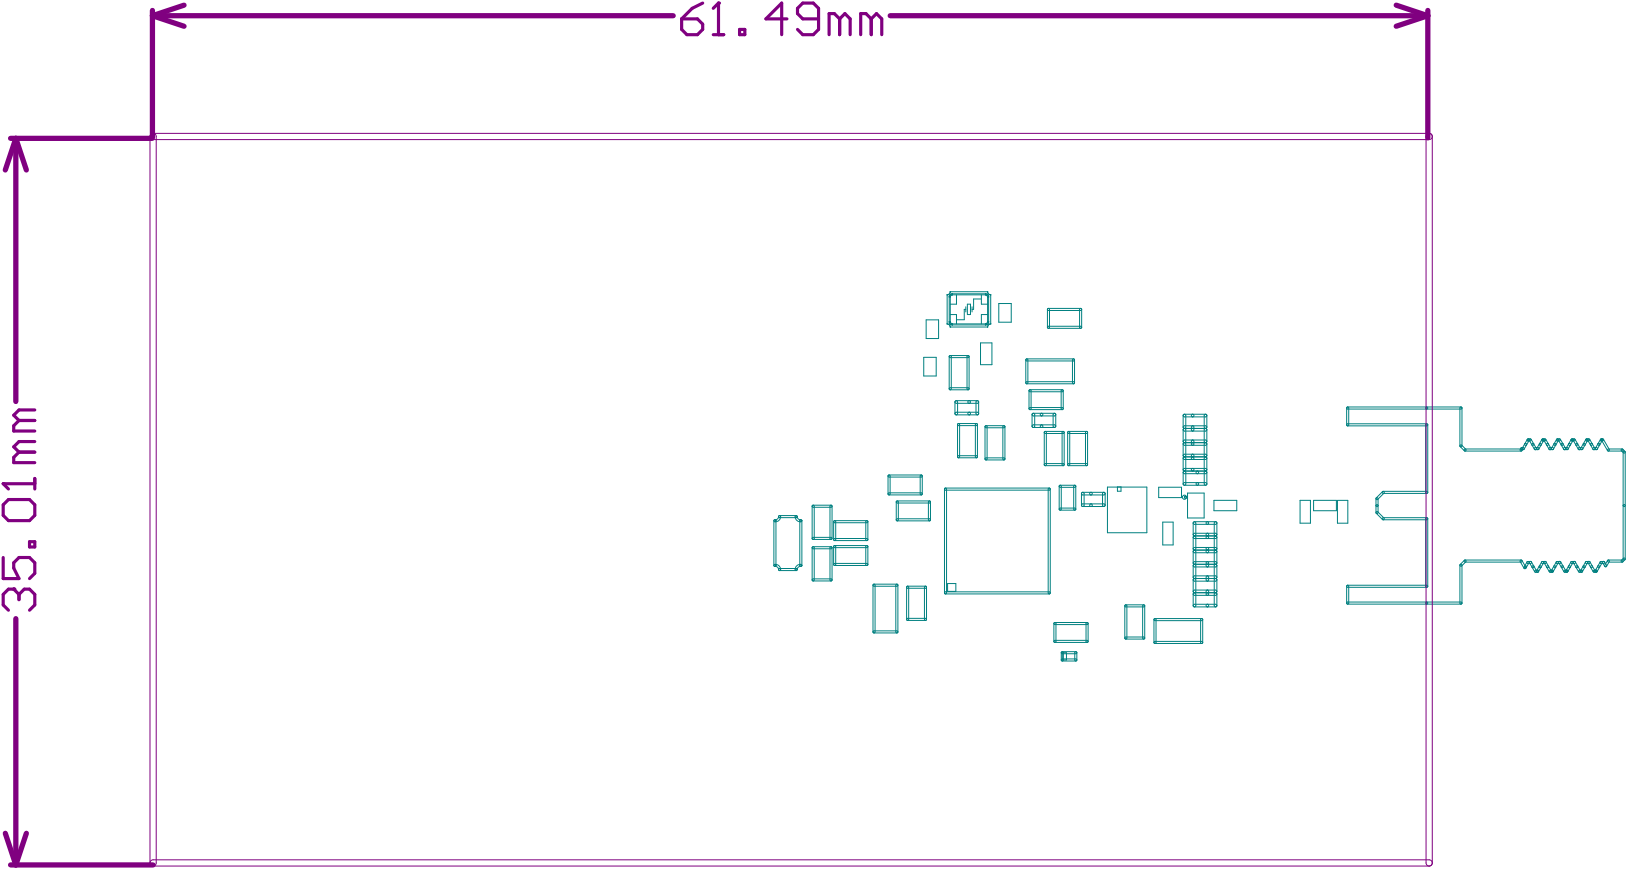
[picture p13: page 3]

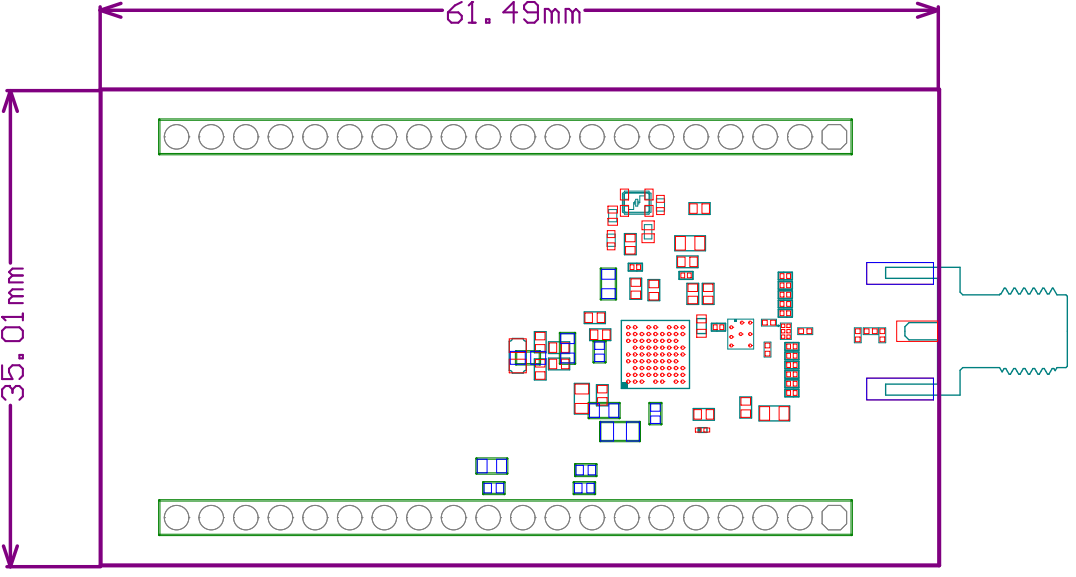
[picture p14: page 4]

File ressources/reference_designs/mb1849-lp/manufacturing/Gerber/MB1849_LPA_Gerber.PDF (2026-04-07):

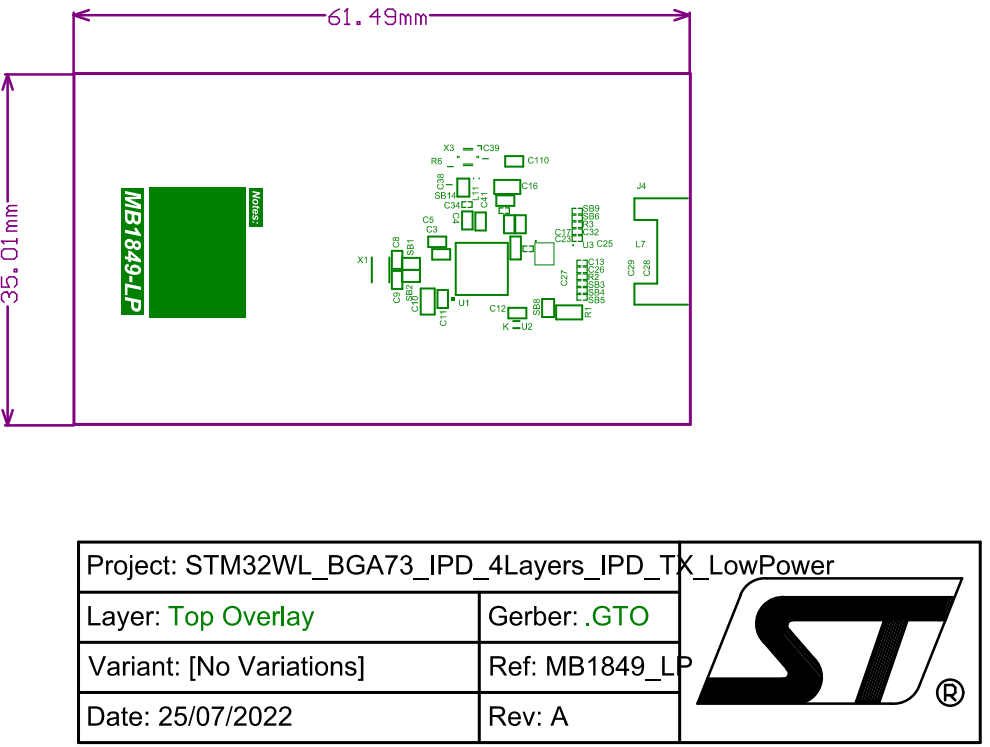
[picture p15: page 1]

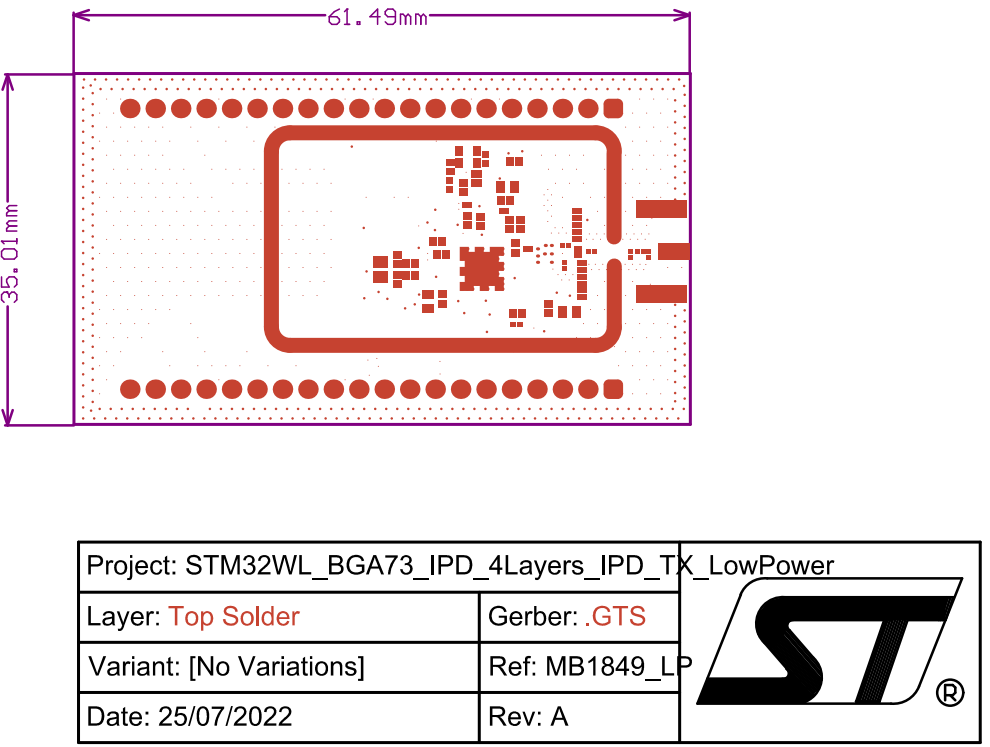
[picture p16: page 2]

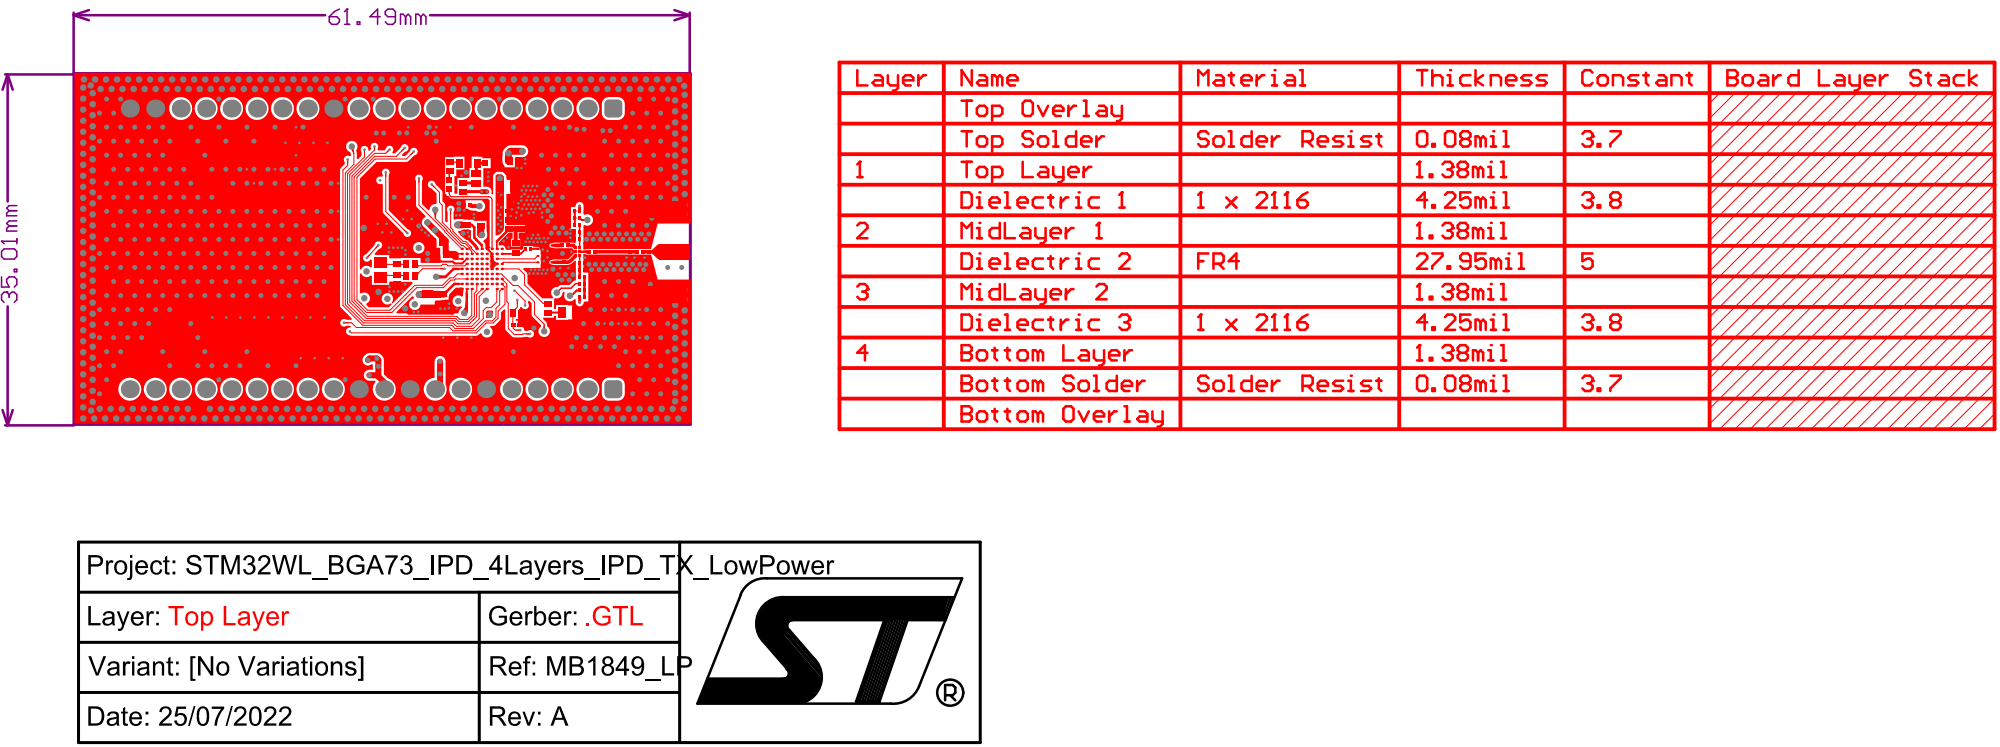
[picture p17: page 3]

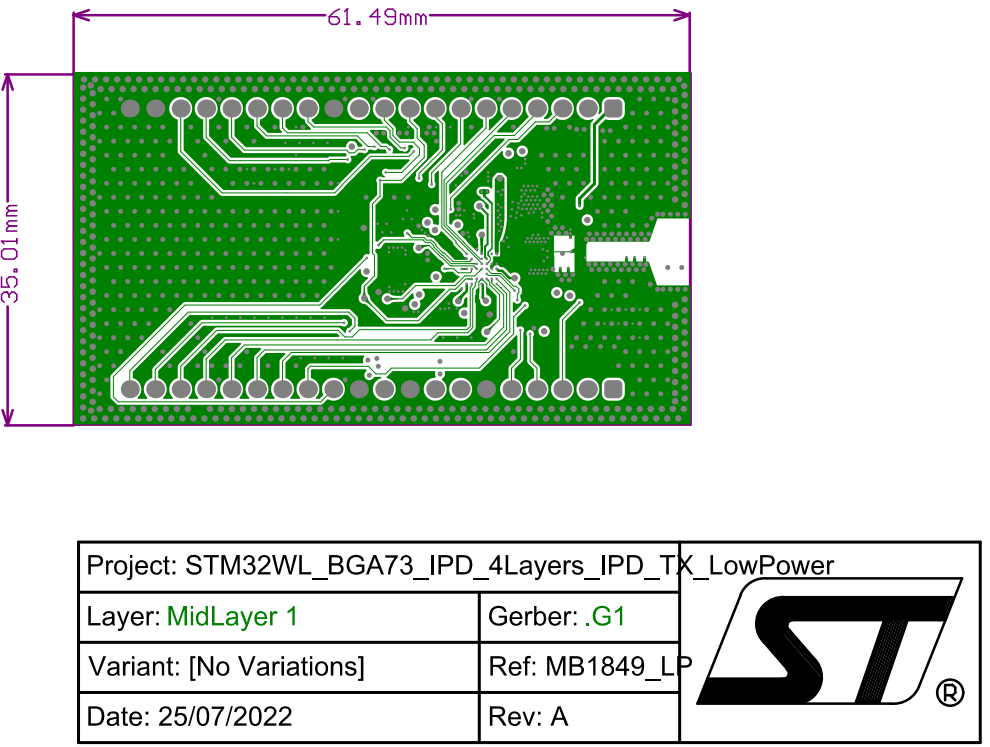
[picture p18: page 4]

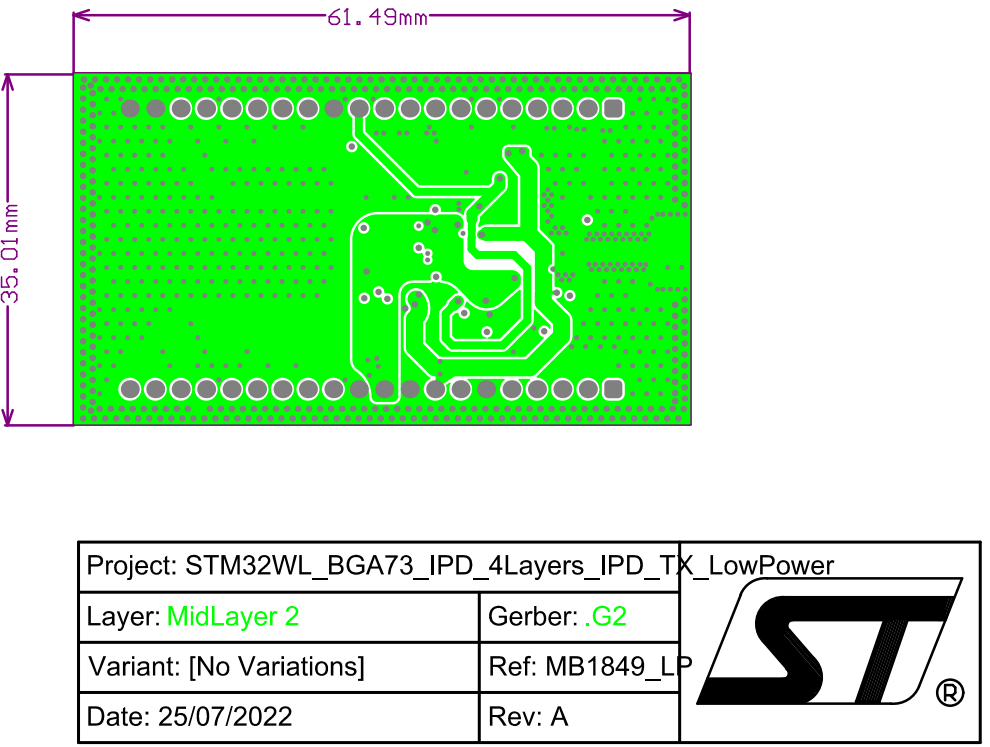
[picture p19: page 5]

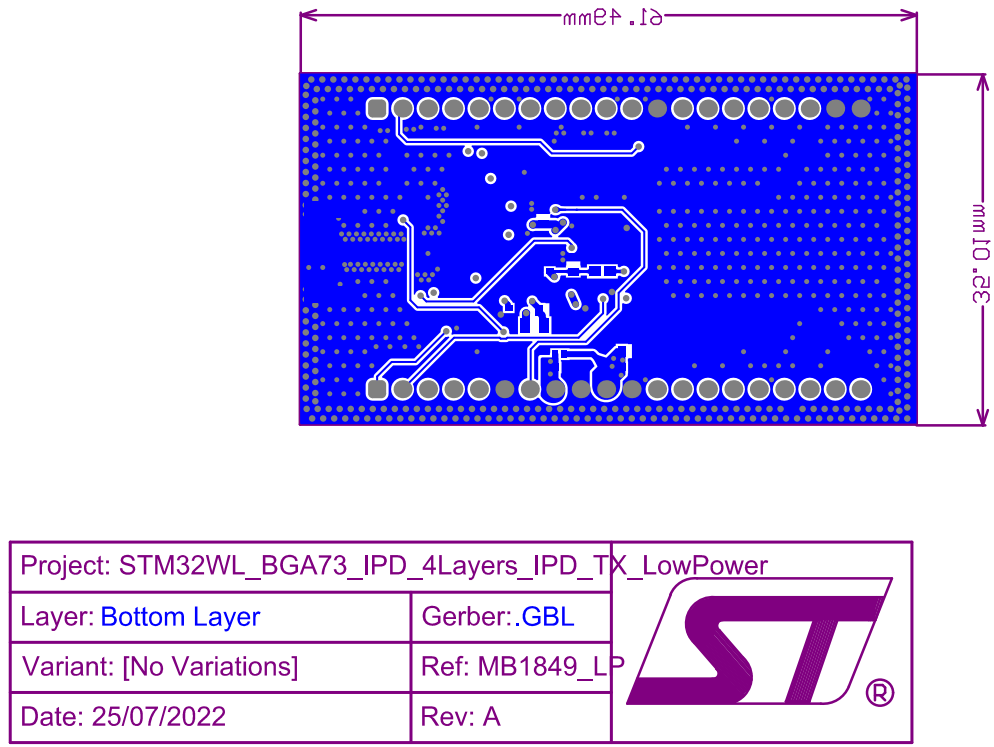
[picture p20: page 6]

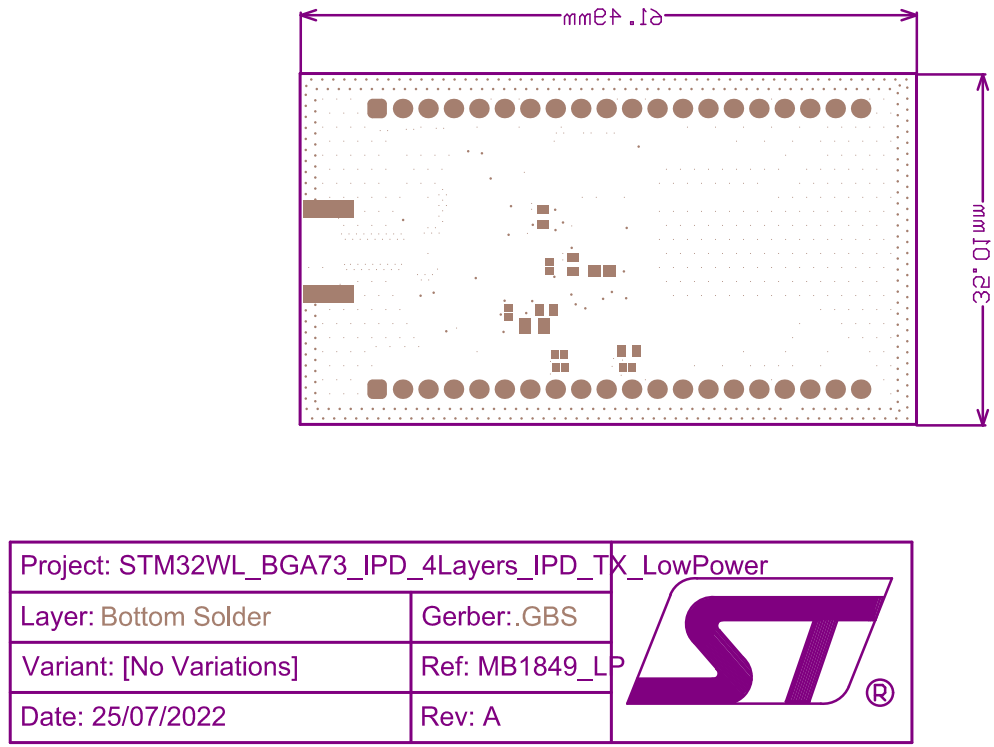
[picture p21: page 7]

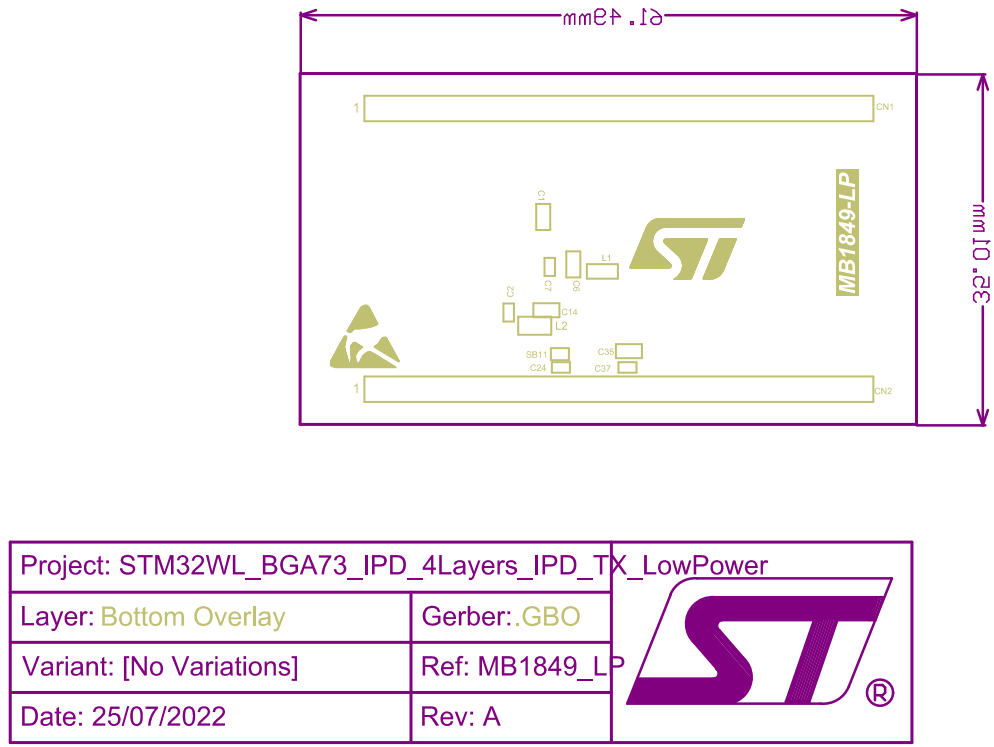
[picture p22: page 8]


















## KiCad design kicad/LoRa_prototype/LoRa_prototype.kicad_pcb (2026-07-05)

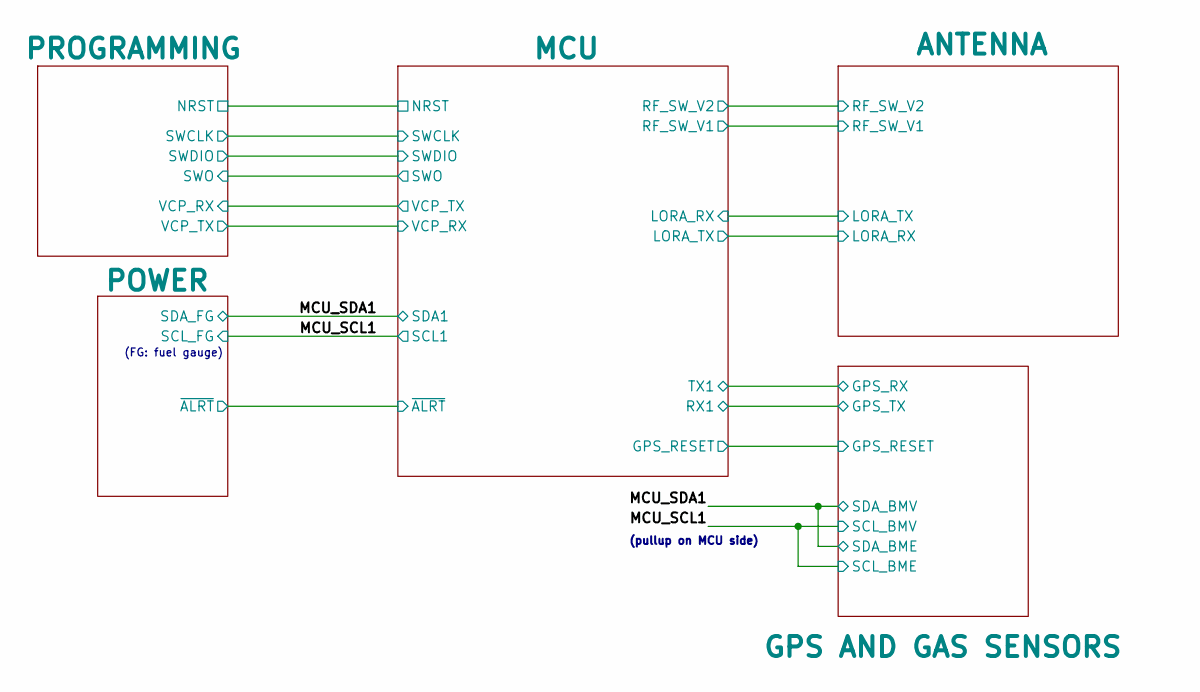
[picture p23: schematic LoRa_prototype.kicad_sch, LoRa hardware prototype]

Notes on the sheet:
(FG: fuel gauge)
(pullup on MCU side)

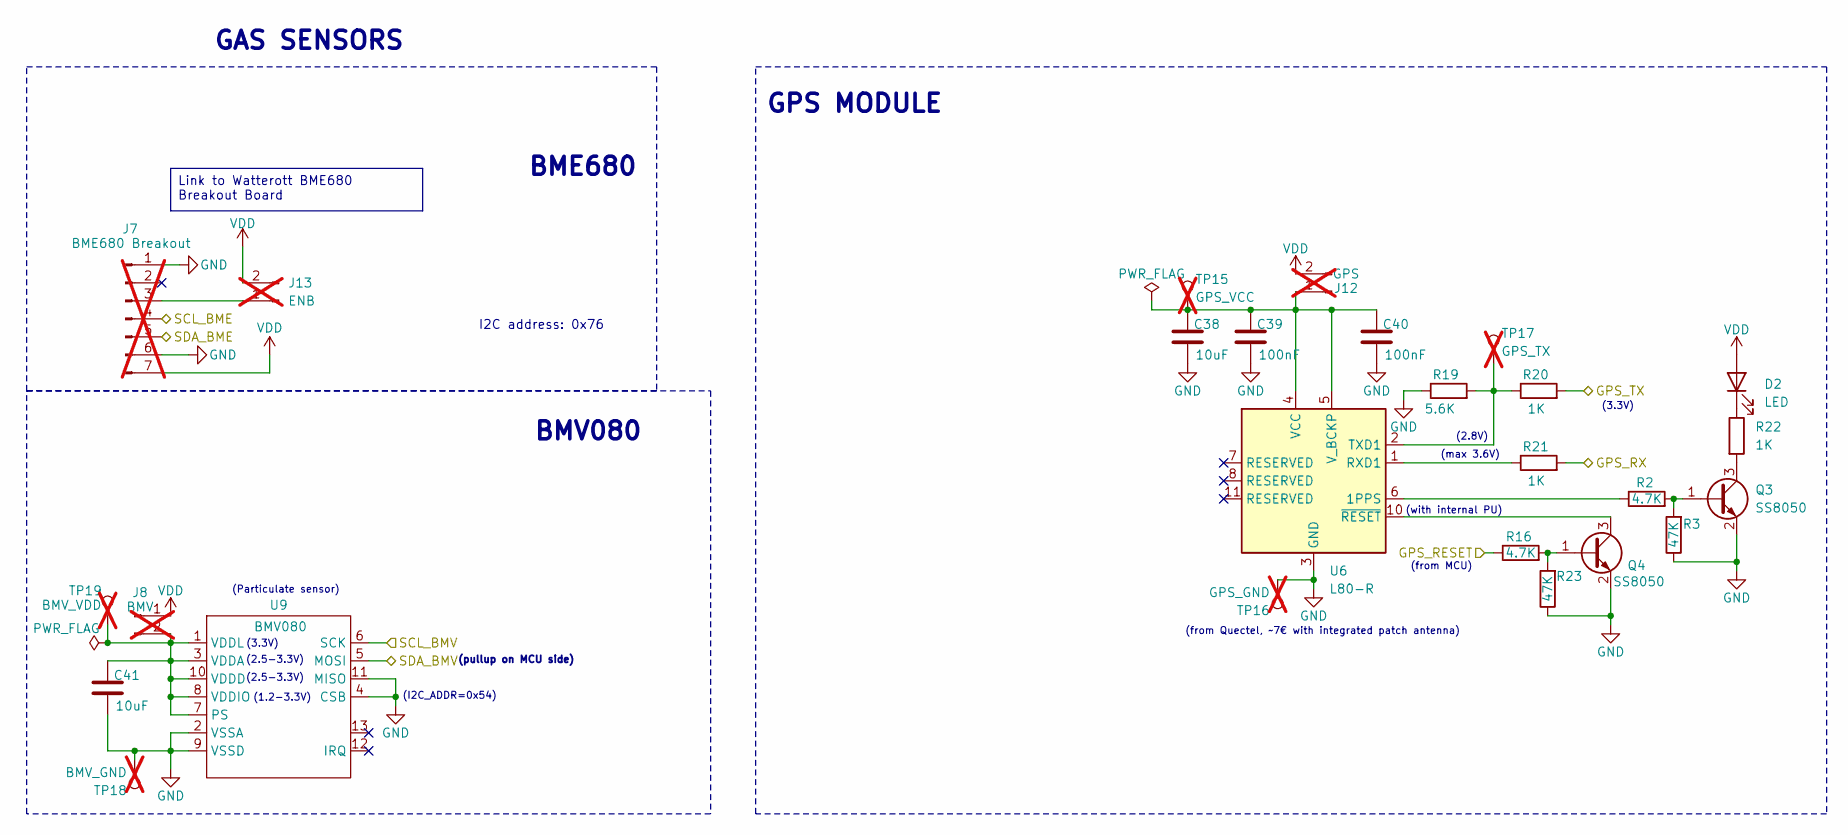
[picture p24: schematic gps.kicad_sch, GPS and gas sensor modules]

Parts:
C38, C41: 10uF; C_0603_1608Metric
C39: 100nF; C_0402_1005Metric
C40: 100nF; C_0603_1608Metric
D2: LED; LED_0805_2012Metric
J7: BME680 Breakout; PinSocket_1x07_P2.54mm_Vertical; not fitted
J8: BMV; PinHeader_1x02_P2.54mm_Vertical; not fitted
J12: GPS; PinHeader_1x02_P2.54mm_Vertical; not fitted
J13: ENB; PinHeader_1x02_P2.54mm_Vertical; not fitted
Q3, Q4: SS8050; SOT-23
R2, R16: 4.7K; R_0805_2012Metric
R3, R23: 47K; R_0805_2012Metric
R19: 5.6K; R_0805_2012Metric
R20, R21, R22: 1K; R_0805_2012Metric
TP15: GPS_VCC; TestPoint_Pad_2.0x2.0mm; not fitted
TP16: GPS_GND; TestPoint_Pad_2.0x2.0mm; not fitted
TP17: GPS_TX; TestPoint_Pad_2.0x2.0mm; not fitted
TP18: BMV_GND; TestPoint_Pad_2.0x2.0mm; not fitted
TP19: BMV_VDD; TestPoint_Pad_2.0x2.0mm; not fitted
U6: L80-R; Quectel_L80-R
U9: BMV080; CON_5035661302_MOL; LCSC C587979

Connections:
/GPS AND GAS SENSORS/GPS_RESET: R16.1; also elsewhere on the board
/MCU/RX1: R20.2; also elsewhere on the board
/MCU/TX1: R21.2; also elsewhere on the board
/MCU_SCL1: J7.4, U9.6 (SCK); also elsewhere on the board
/MCU_SDA1: J7.5, U9.5 (MOSI); also elsewhere on the board
GND: C38.2, C39.2, C40.2, C41.2, J7.1, J7.6, Q3.2 (E), Q4.2 (E), R3.1, R19.1, R23.1, TP16.1 (1_1), TP18.1 (1_1), U6.3 (GND), U6.12 (GND), U9.2 (VSSA), U9.4 (CSB), U9.9 (VSSD), U9.11 (MISO); also elsewhere on the board
unnamed: D2.1 (K), R22.1
unnamed: C41.1, J8.2, TP19.1 (1_1), U9.1 (VDDL), U9.3 (VDDA), U9.7 (PS), U9.8 (VDDIO), U9.10 (VDDD)
unnamed: C38.1, C39.1, C40.1, J12.1, TP15.1 (1_1), U6.4 (VCC), U6.5 (V_BCKP)
unnamed: J7.3, J13.1
unnamed: Q3.1 (B), R2.2, R3.2
unnamed: Q3.3 (C), R22.2
unnamed: Q4.1 (B), R16.2, R23.2
unnamed: Q4.3 (C), U6.10 (~RESET)
unnamed: R2.1, U6.6 (1PPS)
unnamed: R21.1, U6.1 (RXD1)
unnamed: R19.2, R20.1, TP17.1 (1_1), U6.2 (TXD1)
VDD: D2.2 (A), J7.7, J8.1, J12.2, J13.2; also elsewhere on the board

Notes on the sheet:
BME680
(from MCU)
BMV080
(max 3.6V)
(with internal PU)
(I2C_ADDR=0x54)
(2.8V)
(from Quectel, ~7€ with integrated patch antenna)
GPS MODULE
(Particulate sensor)
GAS SENSORS
(3.3V)
(pullup on MCU side)
(2.5-3.3V)
I2C address: 0x76
(1.2-3.3V)
Link to Watterott BME680 Breakout Board

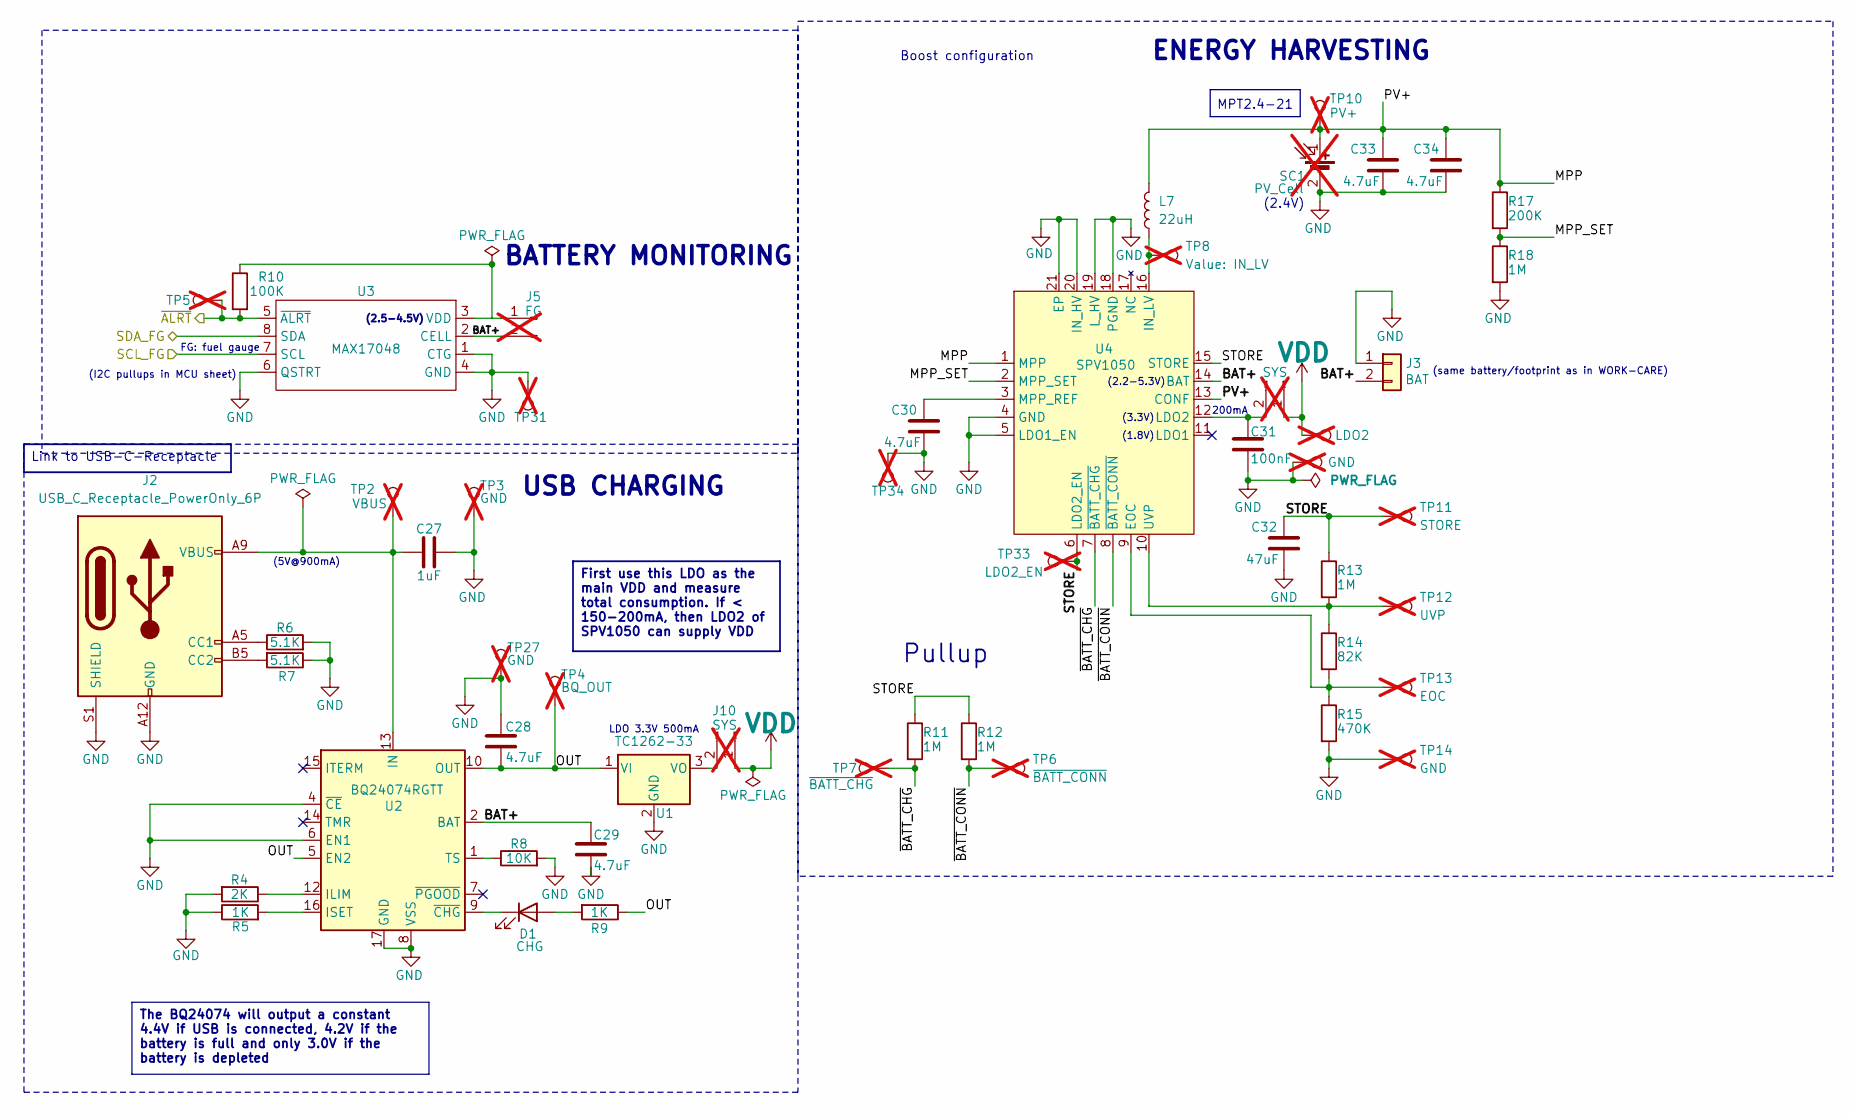
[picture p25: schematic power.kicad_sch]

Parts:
C27: 1uF; C_0603_1608Metric; LCSC C1592
C28, C29: 4.7uF; C_0603_1608Metric; LCSC C19666
C30, C33, C34: 4.7uF; C_0603_1608Metric
C31: 100nF; C_0402_1005Metric
C32: 47uF; C_0805_2012Metric
D1: CHG; LED_0805_2012Metric; LCSC C94740
J2: USB_C_Receptacle_PowerOnly_6P; UC17-0B06F68011
J3: BAT; JST_GH_SM02B-GHS-TB_1x02-1MP_P1.25mm_Horizontal; LCSC C189893
J5: FG; PinHeader_1x02_P2.54mm_Vertical; not fitted
J10, J15: SYS; PinHeader_1x02_P2.54mm_Vertical; not fitted
L7: 22uH; PSPMAA0402-220M-ANP
R4: 2K; R_0805_2012Metric; LCSC C4177
R5: 1K; R_0805_2012Metric; LCSC C21190
R6, R7: 5.1K; R_0805_2012Metric
R8: 10K; R_0805_2012Metric; LCSC C25804
R9: 1K; R_0805_2012Metric; LCSC C20686
R10: 100K; R_0805_2012Metric
R11, R12, R13, R18: 1M; R_0805_2012Metric
R14: 82K; R_0603_1608Metric
R15: 470K; R_0805_2012Metric
R17: 200K; R_0805_2012Metric
SC1: PV_Cell; MPT2.4-21; not fitted
TP2: VBUS; TestPoint_Pad_2.0x2.0mm; not fitted
TP3, TP14, TP27, TP28, TP31, TP34: GND; TestPoint_Pad_2.0x2.0mm; not fitted
TP4: BQ_OUT; TestPoint_Pad_2.0x2.0mm; not fitted
TP5: ~{ALRT}; TestPoint_Pad_2.0x2.0mm; not fitted
TP6: ~{BATT_CONN}; TestPoint_Pad_2.0x2.0mm; not fitted
TP7: ~{BATT_CHG}; TestPoint_Pad_2.0x2.0mm; not fitted
TP8: IN_LV; TestPoint_Pad_2.0x2.0mm; not fitted
TP9: LDO2; TestPoint_Pad_2.0x2.0mm; not fitted
TP10: PV+; TestPoint_Pad_2.0x2.0mm; not fitted
TP11: STORE; TestPoint_Pad_2.0x2.0mm; not fitted
TP12: UVP; TestPoint_Pad_2.0x2.0mm; not fitted
TP13: EOC; TestPoint_Pad_2.0x2.0mm; not fitted
TP33: LDO2_EN; TestPoint_Pad_2.0x2.0mm; not fitted
U1: TC1262-33; SOT-223-3
U2: BQ24074RGTT; VQFN-16-1EP_3x3mm_P0.5mm_EP1.6x1.6mm; LCSC C54313
U3: MAX17048; SON50P200X200X80-9N
U4: SPV1050; QFN40P300X300X100-21N

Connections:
/MCU/~ALRT: R10.2, TP5.1 (1_1), U3.5 (~ALRT); also elsewhere on the board
/MCU_SCL1: U3.7 (SCL); also elsewhere on the board
/MCU_SDA1: U3.8 (SDA); also elsewhere on the board
/POWER/BAT+: C29.2, J3.2, J5.2, U2.2 (BAT), U2.3 (BAT), U3.2 (CELL), U4.14 (BAT)
/POWER/MPP: C33.2, C34.2, L7.2, R17.1, SC1.1 (+), TP10.1 (1_1), U4.1 (MPP), U4.13 (CONF)
/POWER/MPP_SET: R17.2, R18.1, U4.2 (MPP_SET)
/POWER/OUT: C28.1, R9.1, TP4.1 (1_1), U1.1 (VI), U2.5 (EN2), U2.10 (OUT), U2.11 (OUT)
/POWER/STORE: C32.2, R11.1, R12.1, R13.1, TP11.1 (1_1), TP33.1 (1_1), U4.6 (LDO2_EN), U4.15 (STORE); also elsewhere on the board
/POWER/~BATT_CHG: R11.2, TP7.1 (1_1), U4.7 (~BATT_CHG)
/POWER/~BATT_CONN: R12.2, TP6.1 (1_1), U4.8 (~BATT_CONN)
GND: C27.2, C28.2, C29.1, C30.1, C31.2, C32.1, C33.1, C34.1, J2.A12 (GND), J2.B12 (GND), J2.S1 (SHIELD), J3.1, R4.2, R5.1, R6.2, R7.1, R8.2, R15.2, R18.2, SC1.2 (-), TP3.1 (1_1), TP14.1 (1_1), TP27.1 (1_1), TP28.1 (1_1), TP31.1 (1_1), TP34.1 (1_1), U1.2 (GND), U2.4 (~CE), U2.6 (EN1), U2.8 (VSS), U2.17 (GND), U3.1 (CTG), U3.4 (GND), U3.6 (QSTRT), U4.4 (GND), U4.5 (LDO1_EN), U4.18 (PGND), U4.19 (L_HV), U4.20 (IN_HV), U4.21 (EP); also elsewhere on the board
unnamed: D1.2 (A), R9.2
unnamed: D1.1 (K), U2.9 (~CHG)
unnamed: J2.A5 (CC1), R6.1
unnamed: J2.B5 (CC2), R7.2
unnamed: J5.1, R10.1, U3.3 (VDD)
unnamed: J10.2, U1.3 (VO)
unnamed: C31.1, J15.2, U4.12 (LDO2)
unnamed: R4.1, U2.12 (ILIM)
unnamed: C27.1, J2.A9 (VBUS), J2.B9 (VBUS), TP2.1 (1_1), U2.13 (IN)
unnamed: R5.2, U2.16 (ISET)
unnamed: R8.1, U2.1 (TS)
unnamed: R14.2, R15.1, TP13.1 (1_1), U4.9 (EOC)
unnamed: L7.1, TP8.1 (1_1), U4.16 (IN_LV)
unnamed: C30.2, U4.3 (MPP_REF)
unnamed: R13.2, R14.1, TP12.1 (1_1), U4.10 (UVP)
VDD: J10.1, J15.1, TP9.1 (1_1); also elsewhere on the board

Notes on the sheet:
Boost configuration
(5V@900mA)
ENERGY HARVESTING
(2.5-4.5V)
200mA
BATTERY MONITORING
MPT2.4-21
(2.2-5.3V)
FG: fuel gauge
(3.3V)
LDO 3.3V 500mA
Pullup
USB CHARGING
(same battery/footprint as in WORK-CARE)
(2.4V)
(I2C pullups in MCU sheet)
(1.8V)
Link to USB-C-Receptacle
First use this LDO as the main VDD and measure total consumption. If < 150-200mA, then LDO2 of SPV1050 can supply VDD
The BQ24074 will output a constant 4.4V if USB is connected, 4.2V if the battery is full and only 3.0V if the battery is depleted

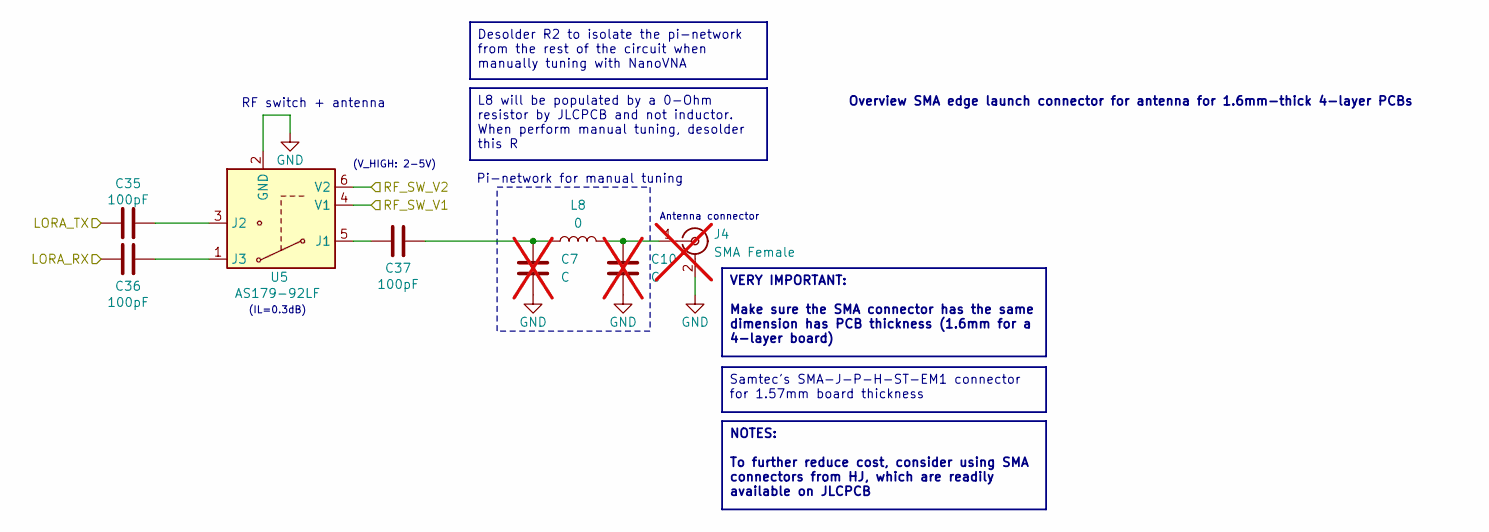
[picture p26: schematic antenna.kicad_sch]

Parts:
C7, C10: C; C_0603_1608Metric; not fitted
C35, C36, C37: 100pF; C_0402_1005Metric
J4: SMA Female; SMA_Samtec_SMA-J-P-H-ST-EM1_EdgeMount; LCSC C5137195; not fitted
L8: 0; L_0603_1608Metric
U5: AS179-92LF; SOT-363_SC-70-6

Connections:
/ANTENNA/LORA_RX: C36.1; also elsewhere on the board
/ANTENNA/LORA_TX: C35.1; also elsewhere on the board
/ANTENNA/RF_SW_V1: U5.4 (V1); also elsewhere on the board
/ANTENNA/RF_SW_V2: U5.6 (V2); also elsewhere on the board
GND: C7.2, C10.2, J4.2 (Ext), U5.2 (GND); also elsewhere on the board
unnamed: C7.1, C37.2, L8.1
unnamed: C10.1, J4.1 (In), L8.2
unnamed: C37.1, U5.5 (J1)
unnamed: C35.2, U5.3 (J2)
unnamed: C36.2, U5.1 (J3)

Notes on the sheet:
(V_HIGH: 2-5V)
Pi-network for manual tuning
RF switch + antenna
(IL=0.3dB)
Antenna connector
Overview SMA edge launch connector for antenna for 1.6mm-thick 4-layer PCBs
Samtec's SMA-J-P-H-ST-EM1 connector for 1.57mm board thickness
Desolder R2 to isolate the pi-network from the rest of the circuit when manually tuning with NanoVNA
L8 will be populated by a 0-Ohm resistor by JLCPCB and not inductor. When perform manual tuning, desolder this R
VERY IMPORTANT: Make sure the SMA connector has the same dimension has PCB thickness (1.6mm for a 4-layer board)
NOTES: To further reduce cost, consider using SMA connectors from HJ, which are readily available on JLCPCB

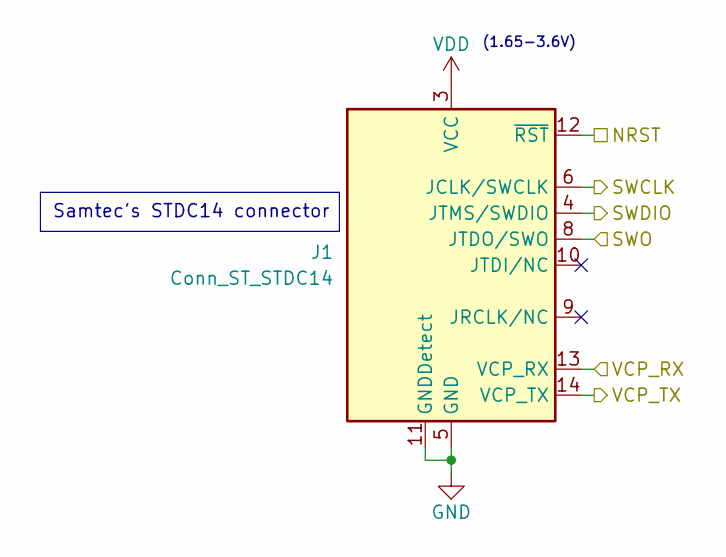
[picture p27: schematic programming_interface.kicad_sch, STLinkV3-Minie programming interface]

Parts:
J1: Conn_ST_STDC14; PinHeader_2x07_P1.27mm_Vertical

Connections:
/MCU/NRST: J1.12 (~RST); also elsewhere on the board
/MCU/SWCLK: J1.6 (JCLK/SWCLK); also elsewhere on the board
/MCU/SWDIO: J1.4 (JTMS/SWDIO); also elsewhere on the board
/MCU/SWO: J1.8 (JTDO/SWO); also elsewhere on the board
/MCU/VCP_RX: J1.14 (VCP_TX); also elsewhere on the board
/MCU/VCP_TX: J1.13 (VCP_RX); also elsewhere on the board
GND: J1.5 (GND), J1.7 (GND), J1.11 (GNDDetect); also elsewhere on the board
VDD: J1.3 (VCC); also elsewhere on the board

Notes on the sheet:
Samtec's STDC14 connector
(1.65-3.6V)

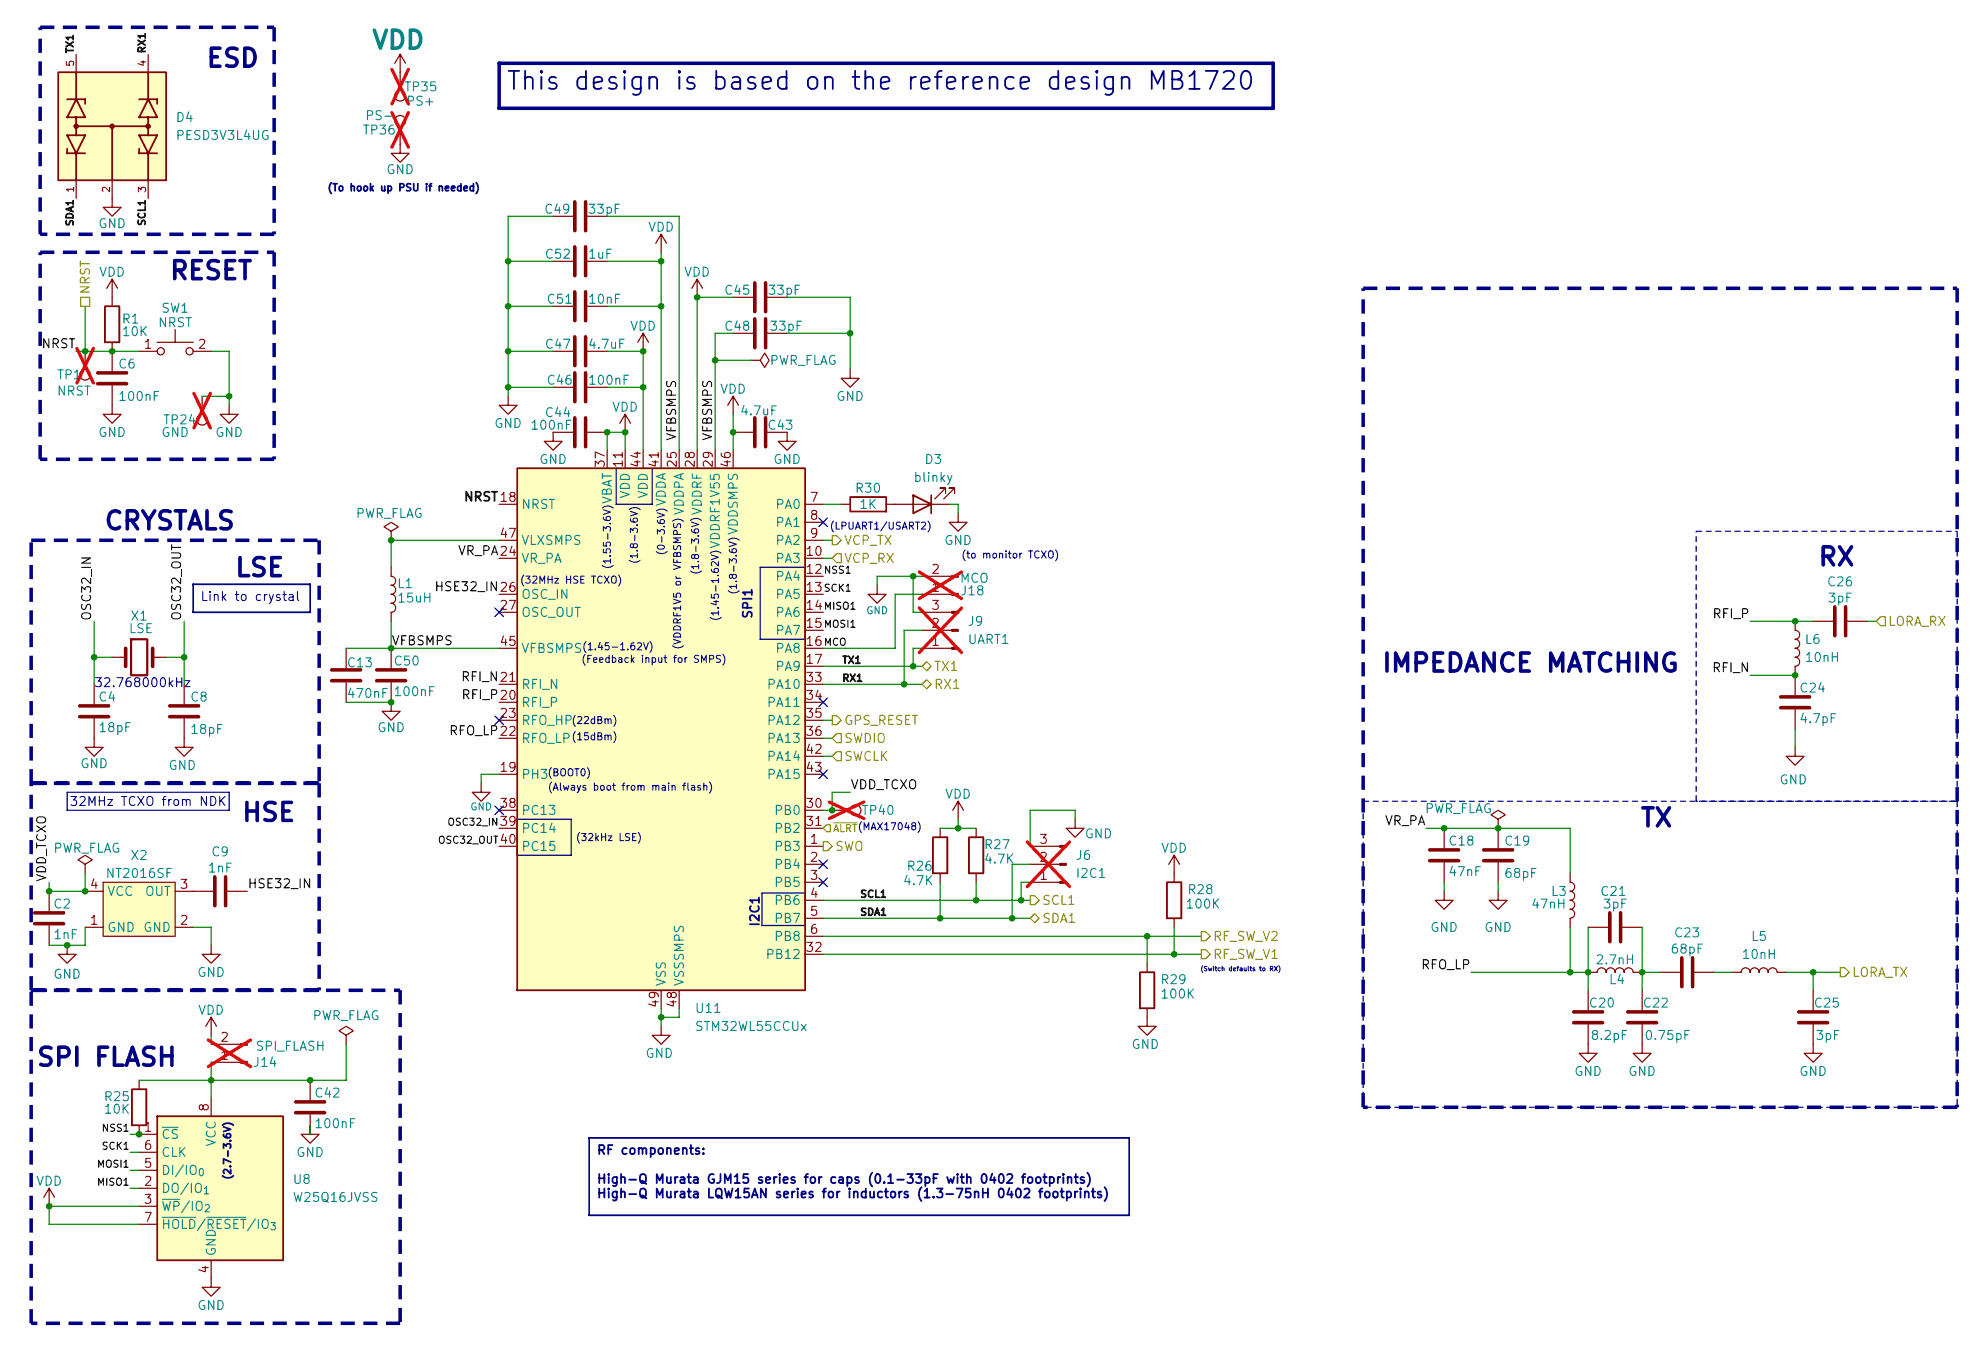
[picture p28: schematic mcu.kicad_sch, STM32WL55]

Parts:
C2, C9: 1nF; C_0402_1005Metric
C4, C8: 18pF; C_0402_1005Metric
C6, C42, C44, C46, C50: 100nF; C_0402_1005Metric
C13: 470nF; C_0603_1608Metric
C18: 47nF; C_0603_1608Metric
C19, C23: 68pF; C_0402_1005Metric
C20: 8.2pF; C_0402_1005Metric
C21, C25, C26: 3pF; C_0402_1005Metric
C22: 0.75pF; C_0402_1005Metric
C24: 4.7pF; C_0402_1005Metric
C43, C47: 4.7uF; C_0402_1005Metric
C45, C48, C49: 33pF; C_0402_1005Metric
C51: 10nF; C_0402_1005Metric
C52: 1uF; C_0402_1005Metric
D3: blinky; LED_0805_2012Metric
D4: PESD3V3L4UG; DIO_PESD3V3L4UG; PARTREV 04
J6: I2C1; PinHeader_1x03_P2.54mm_Vertical; not fitted
J9: UART1; PinHeader_1x03_P2.54mm_Vertical; not fitted
J14: SPI_FLASH; PinHeader_1x02_P2.54mm_Vertical; not fitted
J18: MCO; PinHeader_1x02_P2.54mm_Vertical; not fitted
L1: 15uH; L_0402_1005Metric
L3: 47nH; L_0402_1005Metric
L4: 2.7nH; L_0402_1005Metric
L5, L6: 10nH; L_0402_1005Metric
R1: 10K; R_0603_1608Metric
R25: 10K; R_0805_2012Metric
R26, R27: 4.7K; R_0603_1608Metric
R28, R29: 100K; R_0603_1608Metric
R30: 1K; R_0603_1608Metric
SW1: NRST; TS-1088-AR02016
TP1: NRST; TestPoint_Pad_2.0x2.0mm; not fitted
TP24: GND; TestPoint_Pad_2.0x2.0mm; not fitted
TP35: PS+; TestPoint_THTPad_2.0x2.0mm_Drill1.0mm; not fitted
TP36: PS-; TestPoint_THTPad_2.0x2.0mm_Drill1.0mm; not fitted
TP40: VDDXO; TestPoint_Pad_2.0x2.0mm; not fitted
U8: W25Q16JVSS; SOIC-8_5.3x5.3mm_P1.27mm
U11: STM32WL55CCUx; QFN-48-1EP_7x7mm_P0.5mm_EP5.6x5.6mm
X1: LSE; Crystal_SMD_3215-2Pin_3.2x1.5mm
X2: NT2016SF; NT2016SF TCXO

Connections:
/ANTENNA/LORA_RX: C25.1, L5.2; also elsewhere on the board
/ANTENNA/LORA_TX: C26.2; also elsewhere on the board
/ANTENNA/RF_SW_V1: R28.2, U11.32 (PB12); also elsewhere on the board
/ANTENNA/RF_SW_V2: R29.1, U11.6 (PB8); also elsewhere on the board
/GPS AND GAS SENSORS/GPS_RESET: U11.35 (PA12); also elsewhere on the board
/MCU/HSE32_IN: C9.2, U11.26 (OSC_IN)
/MCU/MCO: J18.1, U11.16 (PA8)
/MCU/MISO1: U8.2 (DO/IO_{1}), U11.14 (PA6)
/MCU/MOSI1: U8.5 (DI/IO_{0}), U11.15 (PA7)
/MCU/NRST: C6.1, R1.2, SW1.1, TP1.1 (1_1), U11.18 (NRST); also elsewhere on the board
/MCU/NSS1: R25.2, U8.1 (~CS), U11.12 (PA4)
/MCU/OSC32_IN: C4.1, U11.39 (PC14), X1.1
/MCU/OSC32_OUT: C8.1, U11.40 (PC15), X1.2
/MCU/RFI_N: C24.1, L6.2, U11.21 (RFI_N)
/MCU/RFI_P: C26.1, L6.1, U11.20 (RFI_P)
/MCU/RFO_LP: C20.1, C21.1, L3.2, L4.1, U11.22 (RFO_LP)
/MCU/RX1: D4.4, J9.2, U11.33 (PA10); also elsewhere on the board
/MCU/SCK1: U8.6 (CLK), U11.13 (PA5)
/MCU/SWCLK: U11.42 (PA14); also elsewhere on the board
/MCU/SWDIO: U11.36 (PA13); also elsewhere on the board
/MCU/SWO: U11.1 (PB3); also elsewhere on the board
/MCU/TX1: D4.5, J9.1, U11.17 (PA9); also elsewhere on the board
/MCU/VCP_RX: U11.10 (PA3); also elsewhere on the board
/MCU/VCP_TX: U11.9 (PA2); also elsewhere on the board
/MCU/VDD_TCXO: C2.1, TP40.1 (1_1), U11.30 (PB0), X2.4 (VCC)
/MCU/VFBSMPS: C13.1, C48.1, C49.2, C50.1, L1.2, U11.25 (VDDPA), U11.29 (VDDRF1V55), U11.45 (VFBSMPS)
/MCU/VR_PA: C18.1, C19.1, L3.1, U11.24 (VR_PA)
/MCU/~ALRT: U11.31 (PB2); also elsewhere on the board
/MCU_SCL1: D4.3, J6.1, R27.2, U11.4 (PB6); also elsewhere on the board
/MCU_SDA1: D4.1, J6.2, R26.2, U11.5 (PB7); also elsewhere on the board
GND: C2.2, C4.2, C6.2, C8.2, C13.2, C18.2, C19.2, C20.2, C22.2, C24.2, C25.2, C42.2, C43.2, C44.2, C45.2, C46.2, C47.2, C48.2, C49.1, C50.2, C51.2, C52.2, D3.1 (K), D4.2, J6.3, J9.3, J18.2, R29.2, SW1.2, TP24.1 (1_1), TP36.1 (1_1), U8.4 (GND), U11.19 (PH3), U11.48 (VSSSMPS), U11.49 (VSS), X2.1 (GND), X2.2 (GND); also elsewhere on the board
unnamed: C21.2, C22.1, C23.1, L4.2
unnamed: C23.2, L5.1
unnamed: D3.2 (A), R30.2
unnamed: C42.1, J14.1, R25.1, U8.8 (VCC)
unnamed: R30.1, U11.7 (PA0)
unnamed: L1.1, U11.47 (VLXSMPS)
unnamed: C9.1, X2.3 (OUT)
VDD: C43.1, C44.1, C45.1, C46.1, C47.1, C51.1, C52.1, J14.2, R1.1, R26.1, R27.1, R28.1, TP35.1 (1_1), U8.3 (~WP/IO_{2}), U8.7 (~HOLD/~RESET/IO_{3}), U11.11 (VDD), U11.28 (VDDRF), U11.37 (VBAT), U11.41 (VDDA), U11.44 (VDD), U11.46 (VDDSMPS); also elsewhere on the board

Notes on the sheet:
SPI FLASH
RESET
IMPEDANCE MATCHING
(1.45-1.62V)
(To hook up PSU if needed)
(LPUART1/USART2)
(1.8-3.6V)
(BOOT0)
(Feedback input for SMPS)
I2C1
(0-3.6V)
(32kHz LSE)
(MAX17048)
CRYSTALS
(Switch defaults to RX)
LSE
(15dBm)
(2.7-3.6V)
32MHz TCXO from NDK
SPI1
(32MHz HSE TCXO)
ESD
(1.55-3.6V)
HSE
(to monitor TCXO)
(22dBm)
(VDDRF1V5 or VFBSMPS)
32.768000kHz
(Always boot from main flash)
RF components: High-Q Murata GJM15 series for caps (0.1-33pF with 0402 footprints) High-Q Murata LQW15AN series for inductors (1.3-75nH 0402 footprints)
This design is based on the reference design MB1720
Link to crystal

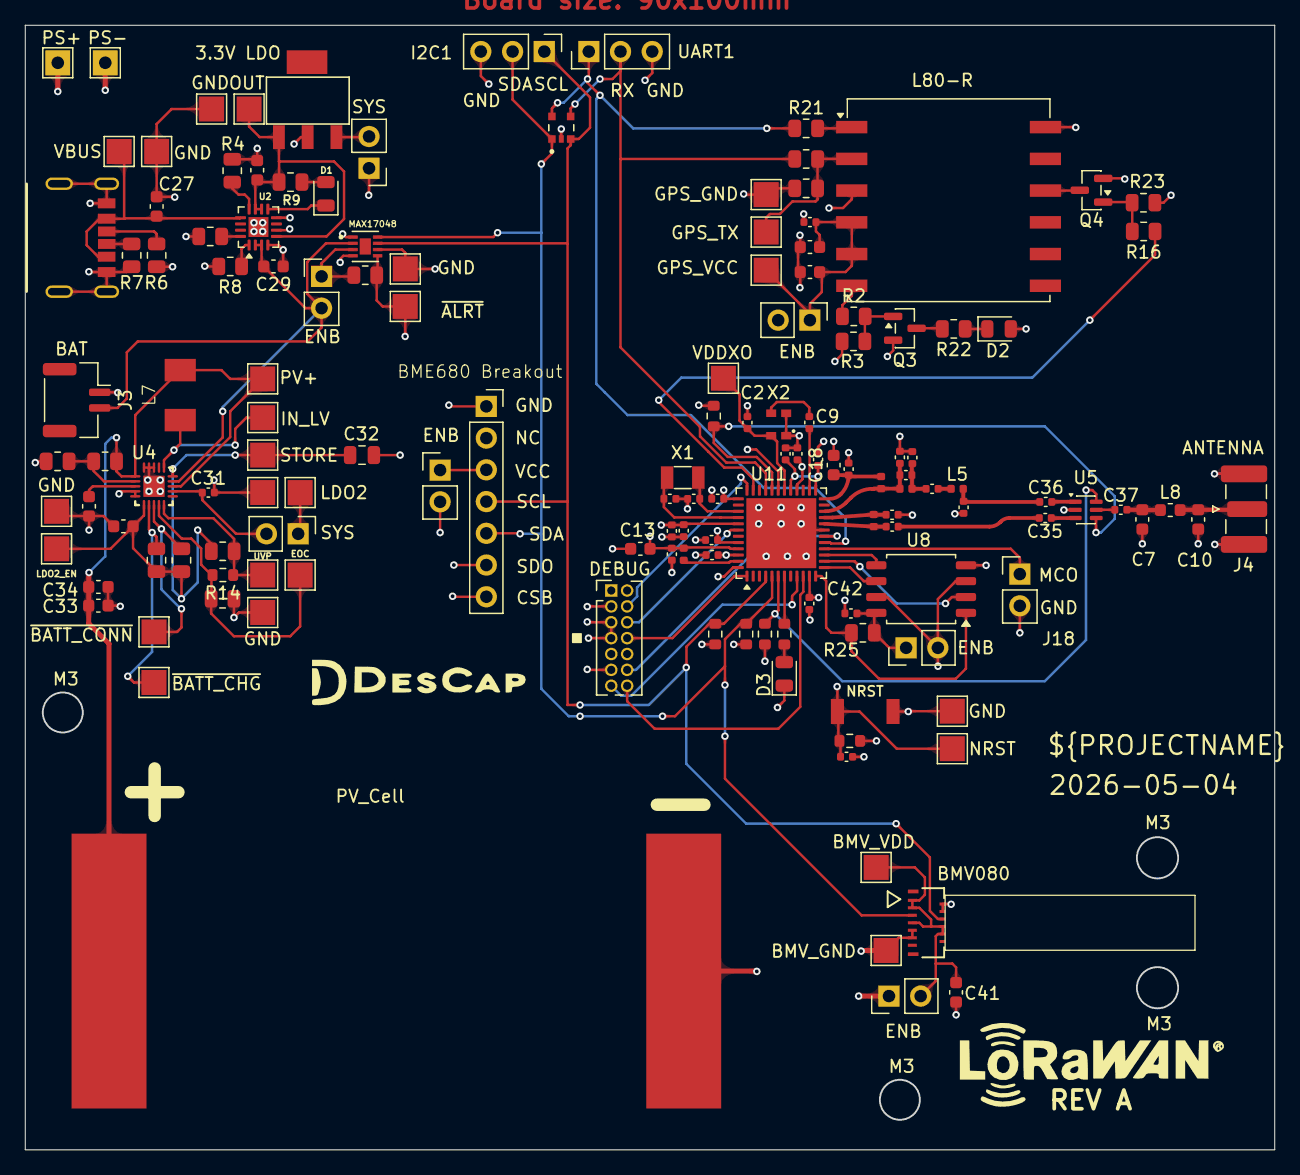
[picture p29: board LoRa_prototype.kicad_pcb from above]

Board: 4 copper layers, 100.0 x 90.0 mm, 142 parts (0 on the bottom side), 77 nets.

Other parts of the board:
C32#2: 47uF; C_0805_2012Metric

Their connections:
/POWER/STORE: C32#2.2; also elsewhere on the board
GND: C32#2.1; also elsewhere on the board

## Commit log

2026-04-05 Added first KiCad files (Milestone)
    [LoRa_prototype.kicad_pcb, LoRa_prototype.kicad_sch]
2026-04-07 Added MB1842 reference designs as resource
    [MB1842-HighBand_HighPower-A02_BOM.xlsx, MB1842-HighBand_LowPower-A02_BOM.xlsx, MB1842-LowBand_HighPower-A02_BOM.xlsx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]
2026-04-07 Added MB1849-LP reference design as resource
    [MB1849.PcbLib, MB1849_LP-[No Variations]-A01_BOM.xlsx, MB1849_LP.PrjPcb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]
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2026-04-09 Implement power decoupling in schematic
    [LoRa_prototype.kicad_sch, mcu.kicad_sch]
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2026-04-13 Done RF matching network in schematic
    [LoRa_prototype.kicad_sch, mcu.kicad_sch]
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2026-04-13 Added custom TCXO symbol
    [mcu.kicad_sch]
2026-04-14 Added LSE and HSE crystals to schematic
    [LoRa_prototype.kicad_sch, mcu.kicad_sch]
2026-04-14 Done doing MCU schematic (Milestone)
    [LoRa_prototype.kicad_sch, mcu.kicad_sch]
2026-04-14 Schematic for programming interface done
    [LoRa_prototype.kicad_sch, mcu.kicad_sch, programming_interface.kicad_sch]
2026-04-14 Add SPV1050 symbol in schematic
    [LoRa_prototype.kicad_sch, mcu.kicad_sch, power.kicad_sch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]
2026-04-15 Start power management block in schematic
    [mcu.kicad_sch, power.kicad_sch, programming_interface.kicad_sch]
2026-04-16 Done schematic for SPV1050 (Milestone)
    [LoRa_prototype.kicad_sch, mcu.kicad_sch, power.kicad_sch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]
2026-04-16 Done power block in schematics + ERC passed with 0 errors
    [LoRa_prototype.kicad_sch, antenna.kicad_sch, mcu.kicad_sch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]
2026-04-17 Start schematic for GPS module
    [LoRa_prototype.kicad_sch, antenna.kicad_sch, gps.kicad_sch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]
2026-04-17 Done schematic GPS block with 0 ERC errors (Milestone)
    [LoRa_prototype.kicad_sch, antenna.kicad_sch, gps.kicad_sch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]
2026-04-17 Copied and cleaned up USb charging circuit from WORK-CARE
    1 ERC error
    [LoRa_prototype.kicad_sch, antenna.kicad_sch, gps.kicad_sch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]
2026-04-18 Added I2C pullups for fuel guage
    [LoRa_prototype.kicad_sch, antenna.kicad_sch, gps.kicad_sch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]
2026-04-18 Added footprints and syms for sensor connectors
    [B5B-ZR_LF__SN_.step]
2026-04-18 Started adding gas sensors to schematic
    [antenna.kicad_sch, mcu.kicad_sch, power.kicad_sch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]
2026-04-18 Added footprint and symbol BME688
    [BME688.step]
2026-04-18 Done schematic for GPS and gas sensors (Milestone)
    [LoRa_prototype.kicad_sch, antenna.kicad_sch, gps.kicad_sch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]
2026-04-18 Schematic cleanup (0 ERC violations)
    [LoRa_prototype.kicad_sch, antenna.kicad_sch, gps.kicad_sch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]
2026-04-18 Added more testpoints to schematic
    [antenna.kicad_sch, gps.kicad_sch, mcu.kicad_sch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]
2026-04-18 Added footprints SPV1050 & SPI Flash
    [SPV1050TTR.step, W25Q16JVSSIQ.step, antenna.kicad_sch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]
2026-04-20 Done schematic with 0 ERC errors (Milestone)
    Still need to double/triple check tho
    [LoRa_prototype.kicad_sch, antenna.kicad_sch, gps.kicad_sch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]
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2026-04-20 Added pin headers in schematics
    To activate/deactivate subsystems as well as measure currents
    [LoRa_prototype.kicad_sch, antenna.kicad_sch, gps.kicad_sch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]
2026-04-21 Created separate folders for footprints and 3d models
    [B5B-ZR_LF__SN_.step, BME688.step, DTC143ZEBTL.step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]
2026-04-21 Redone schematic with stm32wl55ccu6
    The original MCU STM32WL55JCI6 is still left on the schematic so come back here if something is messed up
    [mcu.kicad_sch]
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2026-04-21 Grouped items in schematic (only Kicad 10+)
    [gps.kicad_sch, power.kicad_sch]
2026-04-22 Added ref designs for UQFPN MCU
    [MB1720-HighBand_LowPower-A01_BOM.xlsx, MB1789_LP-HighBand_LowPower-A01_BOM.xlsx]
2026-04-22 Removed redundant I2C test pin headers
    [gps.kicad_sch, mcu.kicad_sch, power.kicad_sch]
2026-04-22 Updated component values to match E24 series
    [mcu.kicad_sch, power.kicad_sch]
2026-04-22 Added ESD protection to I2C and UART headers
    [mcu.kicad_sch]
2026-04-23 Added 3.3V 500mA LDO
    [power.kicad_sch]
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2026-04-24 Added 3d model of fuel gauge
    [MAX17048G_T10.step]
2026-04-24 Assigned almost all footprints
    [antenna.kicad_sch, mcu.kicad_sch, power.kicad_sch]
2026-04-25 Added more footprints and 3d models
    [SMA-J-P-H-ST-EM1.step]
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2026-04-25 Schematic & footprint assignment done (Milestone)
    [antenna.kicad_sch, mcu.kicad_sch]
2026-04-26 Started PCB Layout (Milestone)
    [LoRa_prototype.kicad_pcb, gps.kicad_sch, mcu.kicad_sch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]
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2026-04-27 Routed USB and charging IC
    [LoRa_prototype.kicad_pcb, power.kicad_sch]
2026-04-27 Done routing fuel gauge
    [LoRa_prototype.kicad_pcb, power.kicad_sch]
2026-04-27 Done routing power sheet
    [LoRa_prototype.kicad_pcb]
2026-04-27 Done routing gas sensors
    [LoRa_prototype.kicad_pcb, mcu.kicad_sch, power.kicad_sch]
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2026-04-28 Changed decoupling in schematic
    [LoRa_prototype.kicad_pcb, antenna.kicad_sch, gps.kicad_sch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]
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2026-04-28 Routed 1/2 of MCU and SPI_Flash
    [LoRa_prototype.kicad_pcb]
2026-04-28 Routed I2C and ESD protection for MCU
    [LoRa_prototype.kicad_pcb, mcu.kicad_sch]
2026-04-28 Done routing antenna and RF switch
    [LoRa_prototype.kicad_pcb, mcu.kicad_sch]
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2026-04-29 Added KiNotes to project
    [LoRa_prototype.kicad_pcb]
2026-05-01 90% done (before ground and power pour)
    [LoRa_prototype.kicad_pcb, LoRa_prototype.kicad_sch, antenna.kicad_sch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]
2026-05-01 Added thermal vias to all ICs
    [LoRa_prototype.kicad_pcb]
2026-05-01 Connected all items (with 56 DRC violations)
    [LoRa_prototype.kicad_pcb]
2026-05-02 Stable commit (only 11 DRC violations now)
    [LoRa_prototype.kicad_pcb]
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2026-05-02 Adjusted some silkscreen texts (now down to 86 DRC)
    [LoRa_prototype.kicad_pcb]
2026-05-03 Prettified silkscreen layer
    0 errors and 33 warnings in DRC
    [LoRa_prototype.kicad_pcb, power.kicad_sch]
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2026-05-05 Replaced DTC143ZEBTL with basic parts
    [LoRa_prototype.kicad_pcb, gps.kicad_sch, mcu.kicad_sch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]
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
